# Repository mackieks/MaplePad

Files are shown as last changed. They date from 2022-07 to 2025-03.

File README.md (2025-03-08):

# MaplePad🍁<br/>

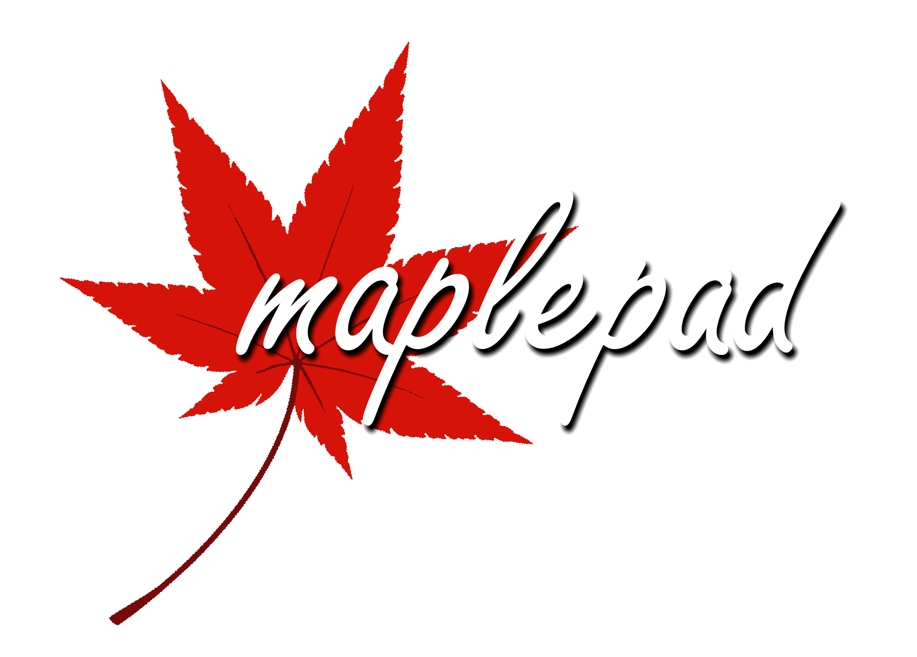
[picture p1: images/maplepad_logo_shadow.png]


MaplePad is an all-in-one Dreamcast controller, VMU, and Purupuru (rumble pack) emulator for Dreamcast portables and custom Dreamcast controllers. It runs on RP2040 and is usable with the Raspberry Pi Pico as well as custom MaplePad PCBs. See the [hardware folder](https://github.com/mackieks/MaplePad/tree/main/hardware) for a wiring diagram.

**Note:** MaplePad is still a WIP. You may experience issues with [Windows CE games](https://segaretro.org/Windows_CE). In almost all problematic titles, disabling VMU and rumble through the MaplePad menu will make the game playable. Check out the [Compatibility List](https://docs.google.com/spreadsheets/d/1JzTGN29Ci8SeuSGkQHLN1p6ayQNWUcsNw77SMujkjbs/edit?usp=sharing) for details!

## Features
With MaplePad you can cycle through 8 200-block internal VMUs with custom icons and colors, use an I2C or SPI OLED display to see the VMU screen in color and at 2x integer scale, and enjoy rumble that is 1:1 with the Performance TremorPak in most retail software (still some minor bugs!)

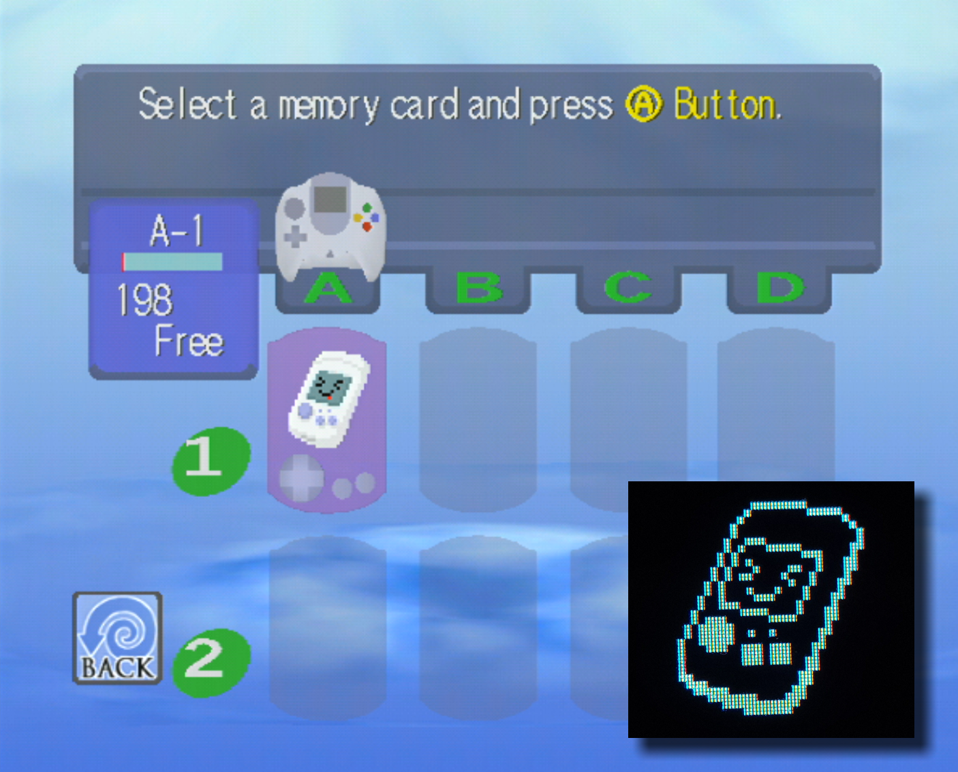
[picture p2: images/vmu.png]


### Feature List:
- [x] Full FT<sub>0</sub> (controller) support including analog joystick and triggers
- [x] Full FT<sub>1</sub> (storage) support for savegames with 1600 blocks of space
- [x] Multipaging for memory card (8 separate 200-block memory cards)
- [x] Full FT<sub>2</sub> (LCD) support with SSD1331 96\*64 color SPI OLED for VMU display (monochrome SSD1306 128\*64 I2C OLED also supported)
- [x] Customizable color palettes for all 8 internal memory cards
- [x] Robust FT<sub>8</sub> (vibration) functionality (WIP)
- [x] Robust FT<sub>3</sub> (timer/RTC) reporting for compatibility purposes (no RTC)
- [x] Basic menu on SSD1306 and SSD1331 OLED for configuring MaplePad behavior (WIP)

### To-do: 
Release v1.6 is gated by the following TODOs
- [ ] Finish menu (button test, VMU palette editor, misc. bugs)
- [ ] Address issues with non-CE games (Crazy Taxi, Blue Stinger, Powerstone 2)
- [ ] Finish FT<sub>8</sub> (vibration) continuous vibration and AST

Future TODOs
- [ ] Fix compatibility with Windows CE games
- [ ] Implement 'fancy' VMU color palettes (gradients, animated backgrounds, etc.)
- [ ] Implement option for DC boot animation on OLED
- [ ] Add external RTC for true FT<sub>3</sub> (timer/RTC) support
- [ ] Implement FT<sub>4</sub> (microphone) support

## Project Showcase
*StrikerDC MaplePad mod by Wesk*

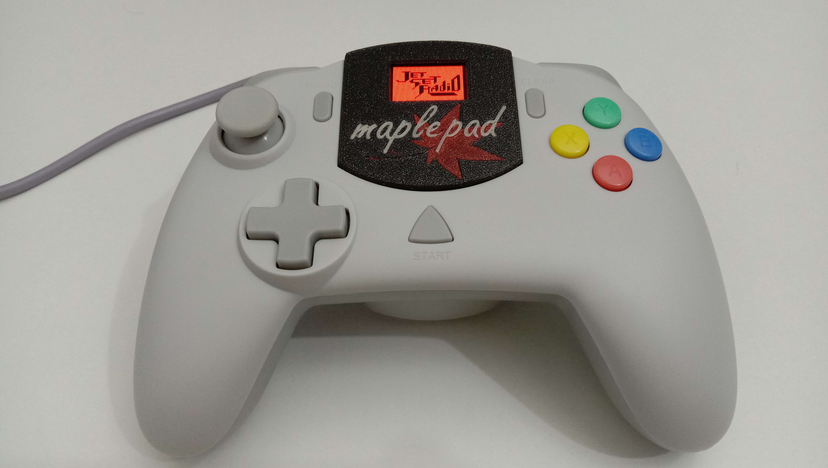
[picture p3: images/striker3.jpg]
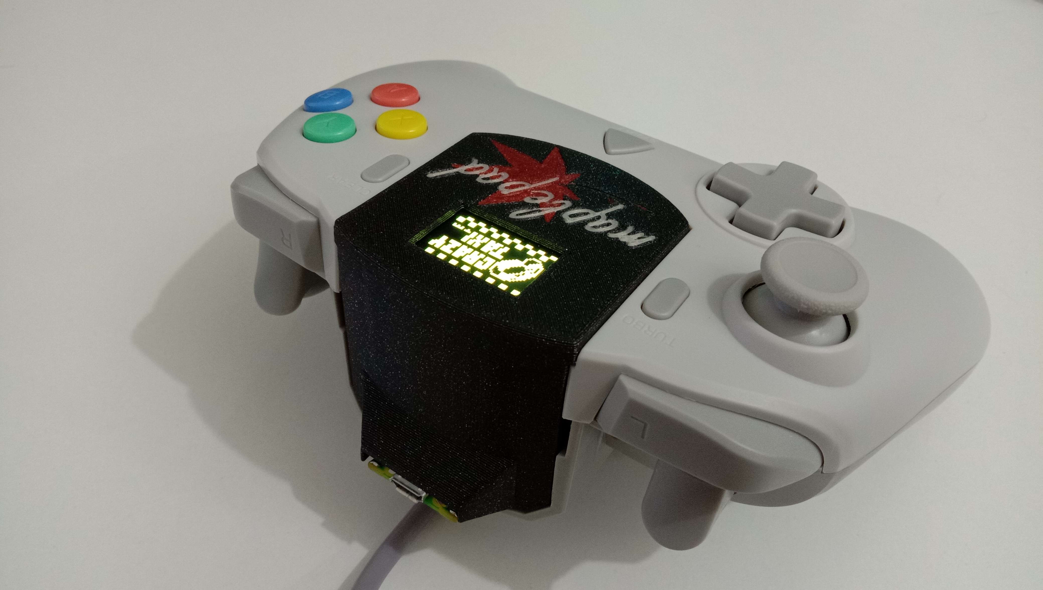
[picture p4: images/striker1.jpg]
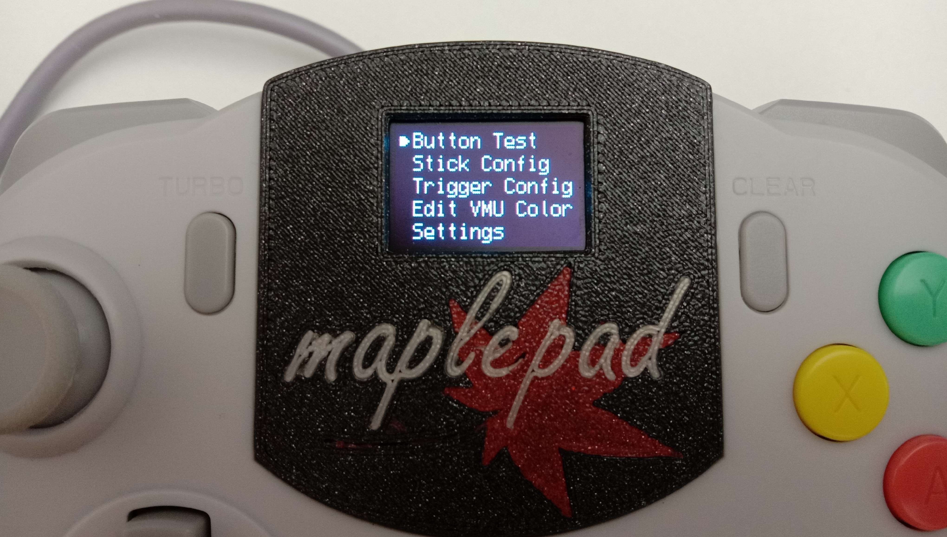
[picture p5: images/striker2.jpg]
  

*MaplePad Arcade Controller with VMU de GamesCare. [link](https://gamescare.com.br/produto/controle-arcade-dreamcast-tela-de-vmu-e-8-vmus-virtuais-na-placa-maple-board/), [video](https://www.youtube.com/watch?v=b0IbSASR3B4/)*

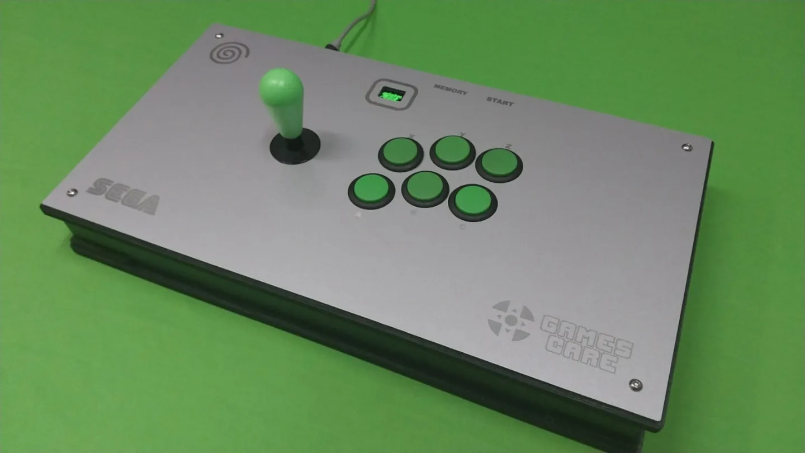
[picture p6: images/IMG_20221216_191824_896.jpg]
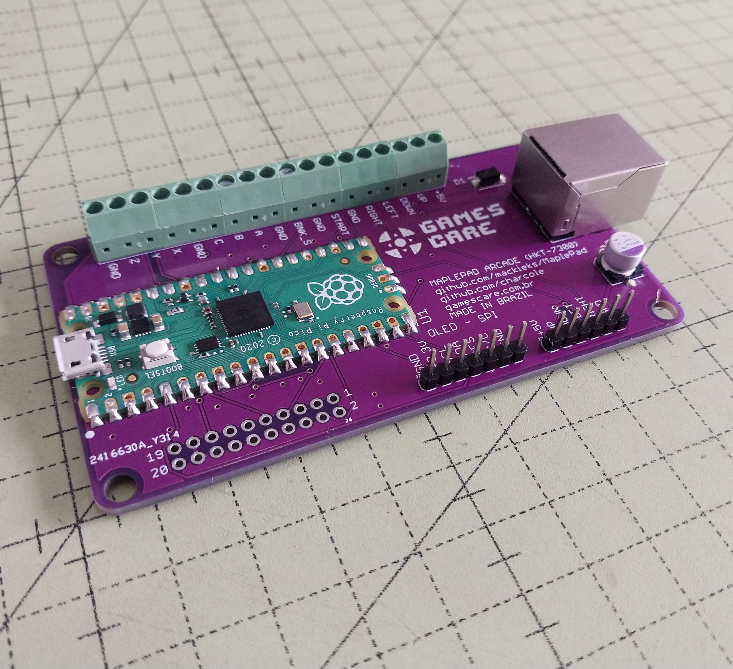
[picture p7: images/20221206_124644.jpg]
 

*Mini Arcade Stick de Mundo Yakara Colombia. Excellent video that showcases MaplePad v1.5 features! [video](https://www.youtube.com/watch?v=jbHO3rEyzZU)*

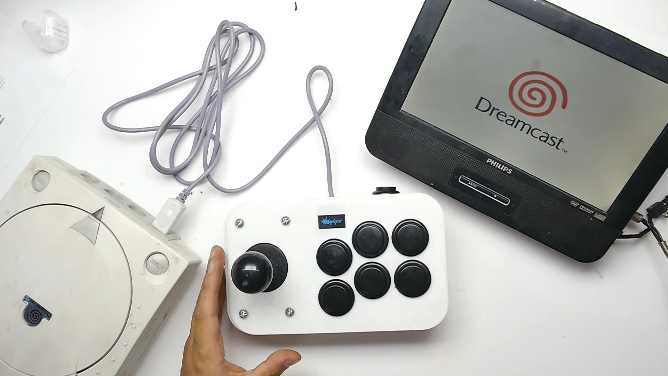
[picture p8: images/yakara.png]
 

*Mini plug'n'play virtual memory card by jounge. [link](https://tieba.baidu.com/p/8465994390)*

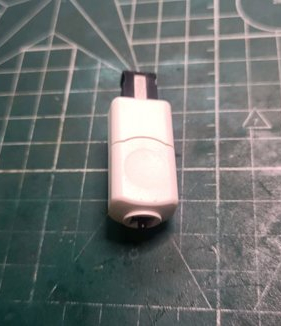
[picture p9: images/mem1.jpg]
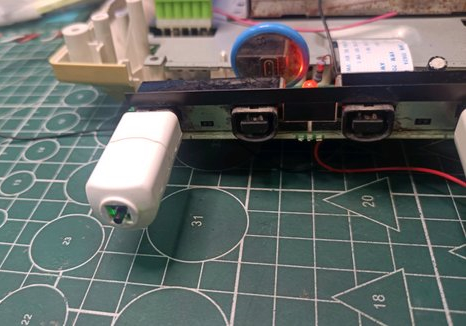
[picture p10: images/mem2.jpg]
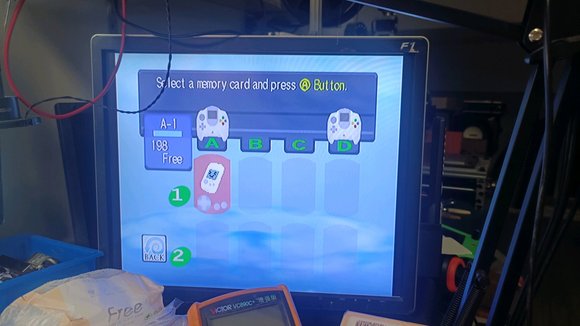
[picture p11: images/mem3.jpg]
  

*Various JAMMA Dreamcast adapters available on AliExpress. [link 1](https://www.aliexpress.us/item/3256805216279752.html), [link 2](https://www.aliexpress.us/item/3256804674679708.html), [video](https://www.youtube.com/shorts/UciW3vM-KWo) (flashing lights warning!)*

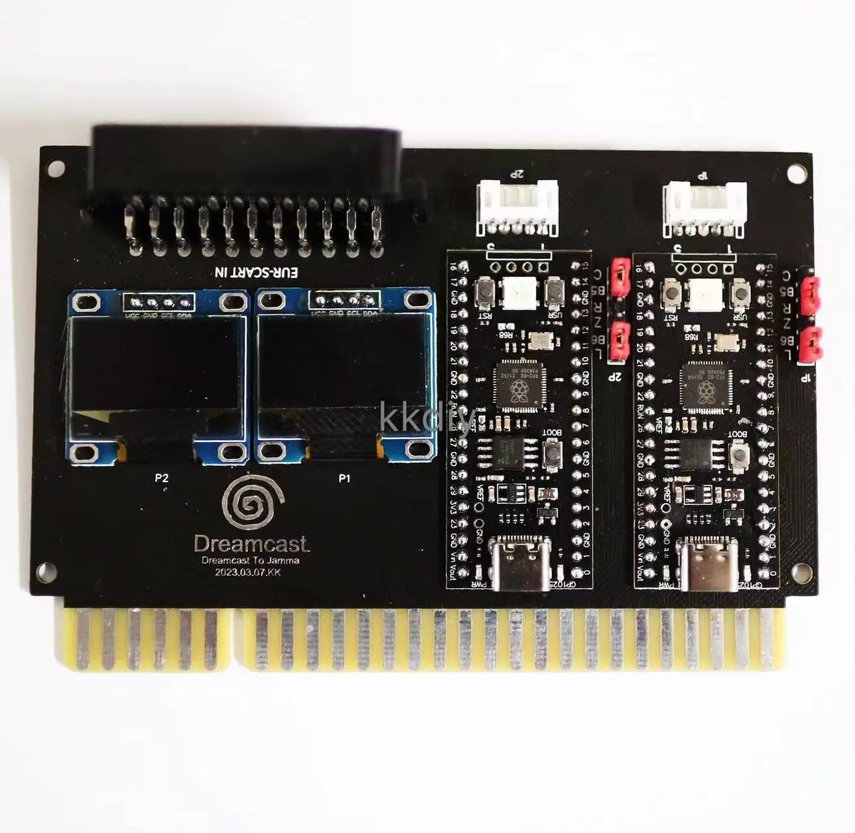
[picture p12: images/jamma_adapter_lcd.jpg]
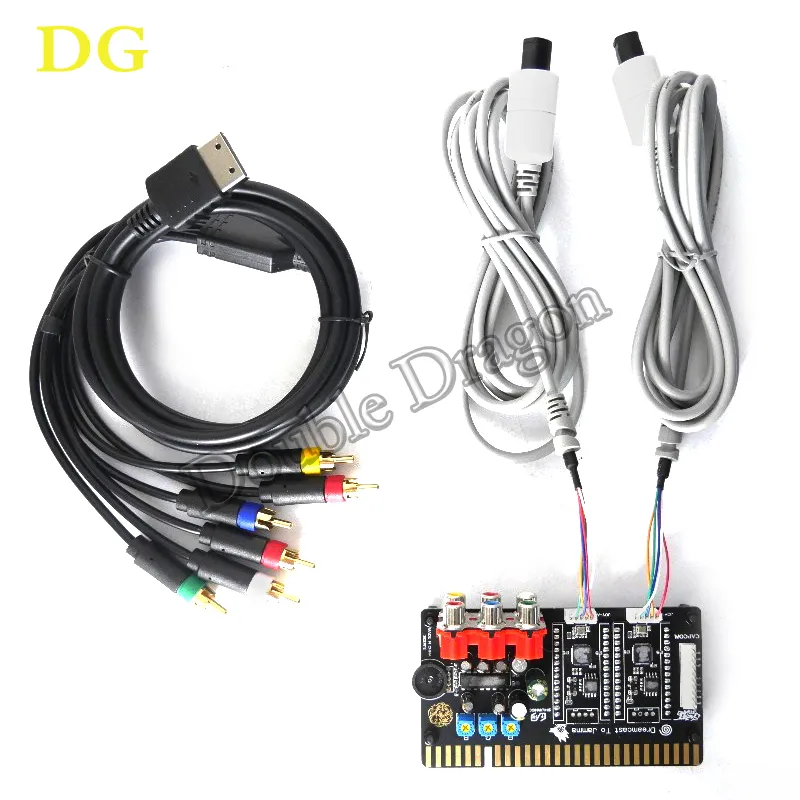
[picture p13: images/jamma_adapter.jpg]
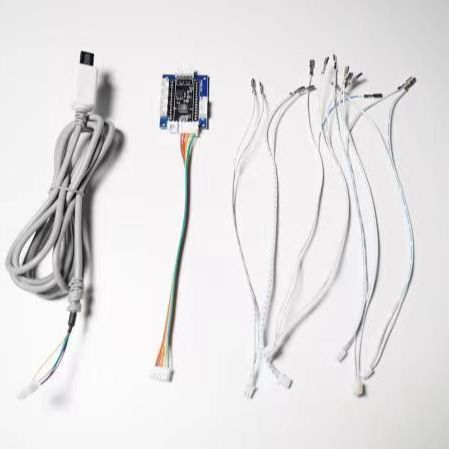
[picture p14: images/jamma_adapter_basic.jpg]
   

*Giant Dreamcast VMU + Arcade Stick by CrazyJojo (code modified). [video](https://www.youtube.com/watch?v=bEA_On7P_g8)*

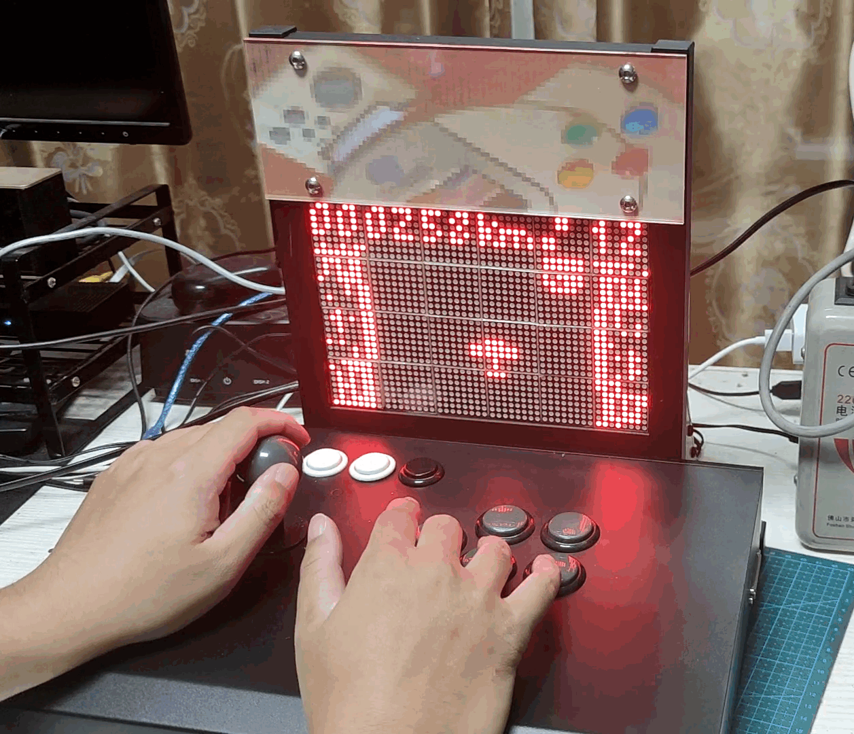
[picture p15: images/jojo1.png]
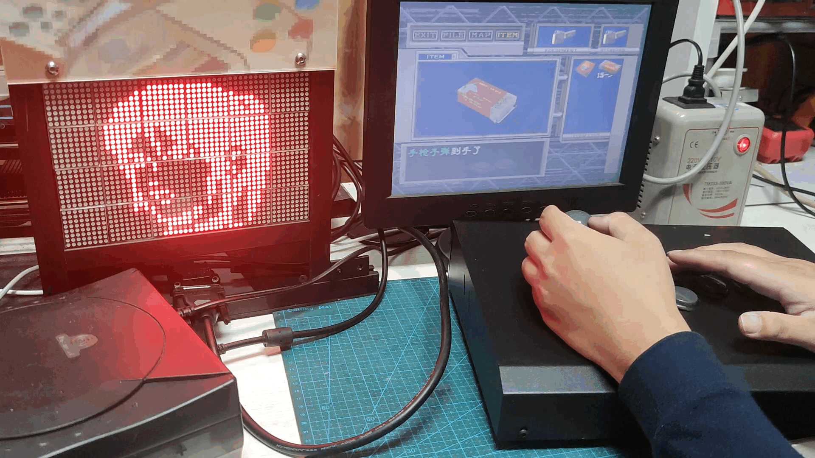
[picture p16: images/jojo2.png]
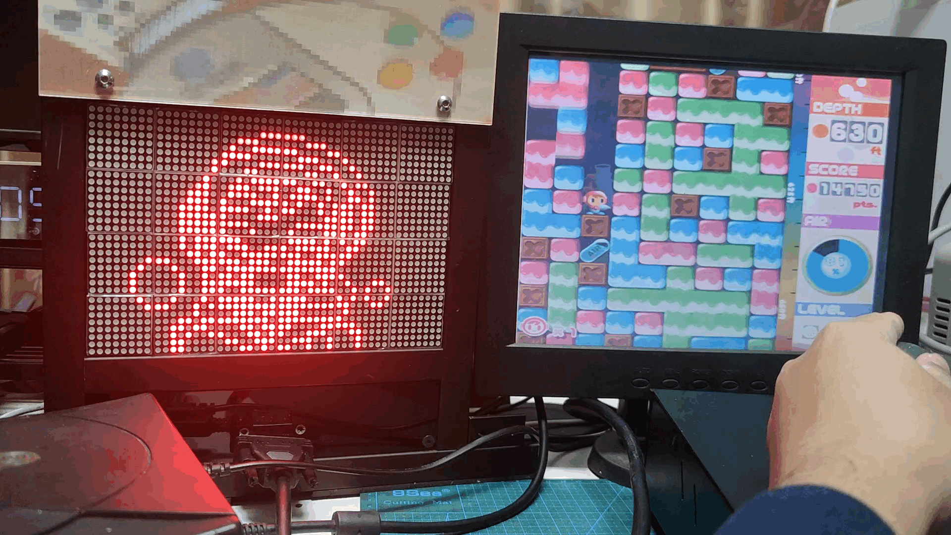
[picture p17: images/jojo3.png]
   

## Dumping VMUs to PC
You can use [picotool](https://github.com/raspberrypi/picotool) to dump VMUs manually. Here's the process:

- Put RP2040 into programming mode with BOOTSEL button and connect it to your PC
- Use picotool to dump whichever VMU page you want: `picotool save -r 10020000 10040000 dump1.bin`

- VMUs start at 0x10020000 and each one is 0x20000 long. So to save page 7, for example, you'd use 
`picotool save -r 100E0000 10100000 dump7.bin`
- Open dump in [VMU Explorer](https://segaretro.org/VMU_Explorer)


## License
<br />This work is licensed under a <a rel="license" href="http://creativecommons.org/licenses/by/4.0/">Creative Commons Attribution 4.0 International License</a>.

Share — copy and redistribute the material in any medium or format <br />
Adapt — remix, transform, and build upon the material for any purpose, even commercially. <br />
Attribution — You must give appropriate credit, provide a link to the license, and indicate if changes were made. <br />

MaplePad is forked from [Charlie Cole's Pop'n Music Controller.](https://github.com/charcole/Dreamcast-PopnMusic)

Special thanks: [Charlie Cole](https://github.com/charcole), [Colton Pawielski](https://github.com/cepawiel) and [Wesk](https://www.youtube.com/channel/UCYAwbbBxi5_LK8WVrD10SUw).

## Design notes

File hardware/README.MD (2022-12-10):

# Raspberry Pi Pico

Wiring diagram for Raspberry Pi Pico: 

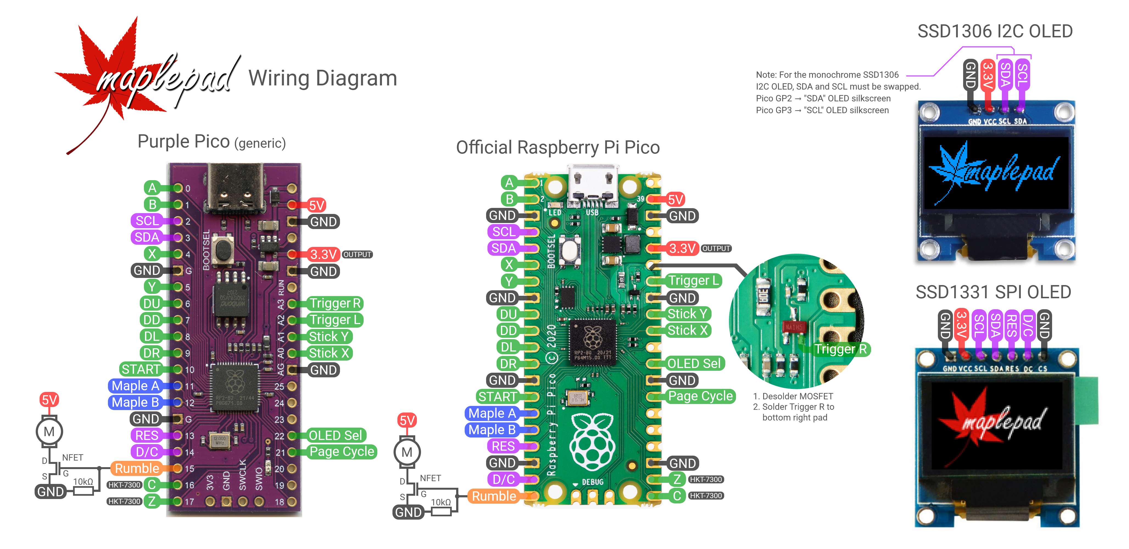
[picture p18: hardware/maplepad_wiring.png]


Notes:
- Do not connect a USB cable to the Pico when it is connected to the Dreamcast. (5V will backfeed to console!)
- The official Raspberry Pi Pico must be modded to access the right trigger pin (ADC3). See the wiring diagram for details.
- For rumble, use an N-channel FET with V<sub>GS(th)</sub> < 3V and I<sub>d</sub> ≥ 1A. Both large Xbox-style ERMs and coin-type vibration motors work well.
- You can add a freewheel diode between 5V and the NFET's drain if you'd like, but it's not necessary for prototyping.
- Connect OLED_SEL to GND to select the SSD1306 OLED. Leave floating to select the SSD1331 OLED.
- When wiring the SSD1306 I2C OLED, SDA and SCL need to be swapped and will not match the silkscreen on the OLED PCB. See the wiring diagram for details.
- The SSD1331 SPI OLED runs at a high clock speed. Use at least 34AWG wire and keep the wires short and direct.

# MaplePad 

Replacement Dreamcast controller PCB for portablizing, using RP2040. EAGLE source, Gerbers, BOM and assembly drawing are available in this directory. (Photo below is of the previous revision which lacked the BOOTSEL button.)



Recommended board fabrication specs: 
- 0.8mm 2-layer PCB
- ENIG (for chipscale BGAs)
- Red soldermask - optional, but in keeping with the Japanese maple theme :) 

JLCPCB may grow the drills under the flash to meet their spec-- this is OK. Also please note that the extremely small castellations often result in many 'crushed barrels' that require manual cleanup.

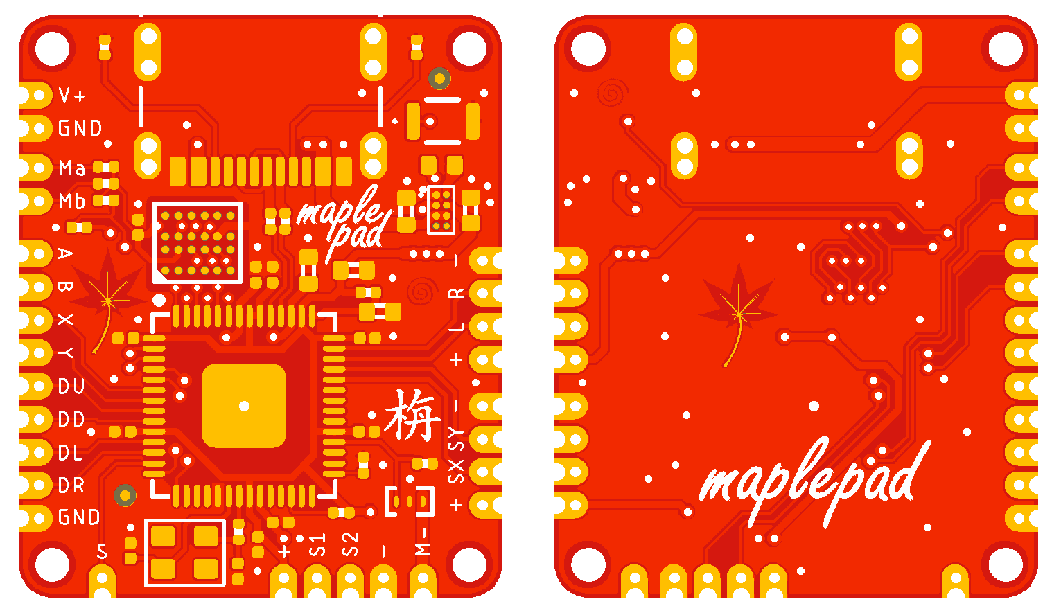
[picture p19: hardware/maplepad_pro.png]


Features:
- [x] 18.5 x 22.4mm 2-layer PCB
- [x] USB-C and BOOTSEL button for programming
- [x] Full Dreamcast controller compatibility
- [x] Analog joystick and triggers
- [x] VMU emulation (8-page VMU, 1600 blocks total)
- [x] SPI/I2C OLED for VMU screen
- [x] Rumble (Purupuru) support (WIP)
- [x] Power from 1.8V - 5.5V

What it doesn't support:
- [ ] Dual analog sticks
- [ ] Dreamcast Microphone
- [ ] Dreamcast Keyboard, Mouse, or Fishing Controller

A future version may support these features.

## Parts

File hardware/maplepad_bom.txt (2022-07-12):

Part   Value              Device                  Package                                                      
C1     10uF               C-USC0402               C0402                  
C2     15pF               C-USC0201               C0201                  
C3     15pF               C-USC0201               C0201                  
C4     10uF               C-USC0402               C0402                  
C5     0.1uF              C-USC0201               C0201                  
C6     0.1uF              C-USC0201               C0201                  
C7     0.1uF              C-USC0201               C0201                  
C8     0.1uF              C-USC0201               C0201                  
C9     0.1uF              C-USC0201               C0201                  
C10    0.1uF              C-USC0201               C0201                  
C11    0.1uF              C-USC0201               C0201                  
C12    1uF                C-USC0402               C0402                  
C13    0.1uF              C-USC0201               C0201                  
C14    0.1uF              C-USC0201               C0201                  
C15    1uF                C-USC0402               C0402                  
C16    2.2uF              C-USC0402               C0402                                   
IC1    RP2040_QFN56       RP2040_QFN56            QFN56_7MM_REDUCEDEPAD  
J2     2171790001         2171790001              2171790001_MOL                          
L1     MCEE1005T1R0MHN    L0402                   R0402                                 
R1     10k                R-US_R0201              R0201                  
R2     5.1k               R-US_R0201              R0201                  
R3     1k                 R-US_R0201              R0201                  
R4     10k                R-US_R0201              R0201                  
R6     200                R-US_R0201              R0201                  
R7     22                 R-US_R0201              R0201                  
R8     22                 R-US_R0201              R0201                  
R9     4.7k               R-US_R0201              R0201                  
R10    4.7k               R-US_R0201              R0201                  
R11    5.1k               R-US_R0201              R0201                  
R12    0-ohm for I2C OLED R-US_R0201              R0201                  
R13    10k                R-US_R0201              R0201                  
R14    1k                 R-US_R0201              R0201                                 
S1     GSNAN0T000101      GSNAN0T000101           GSNAN0T000101                           
U$1    ISL9122A           ISL9122A                ISL9122A               
U$25   W25Q128JVYIQ-TR    W25Q128JVYIQ-TR         WLCSP24                
U1     CSD17585F5T        CSD17585F5T             YJK3_TEX                                
Y1     12MHZ              FA-20H 12.0000MD30Z-K3  CRYSTAL_2.5X2

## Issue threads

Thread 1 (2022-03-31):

Arcade Stick version?

gamecenterjun, 2022-03-31:
Is it possible to make an arcade stick version for this? Basically the same thing, but using C and Z buttons instead of L and R triggers, since digital inputs are better than analog for arcade sticks and games. It would be fantastic if this were possible!

mackieks, 2022-04-05:
Hi! Sure, that's easy. If you don't need VMU LCD functionality, it might be easier for you to start from Charcole's original Pop'n Music controller code, since you wouldn't have to strip out MaplePad's analog stick/trigger code. Either way the edits would be similar.

First you'd need to make some changes to the main controller InfoPacket:

```
void BuildInfoPacket()
{
	InfoPacket.BitPairsMinus1 = (sizeof(InfoPacket) - 7) * 4 - 1;

	InfoPacket.Header.Command = CMD_RESPOND_DEVICE_INFO;
	InfoPacket.Header.Recipient = ADDRESS_DREAMCAST;
	InfoPacket.Header.Sender = ADDRESS_CONTROLLER_AND_SUBS;
	InfoPacket.Header.NumWords = sizeof(InfoPacket.Info) / sizeof(uint);

	InfoPacket.Info.Func = __builtin_bswap32(FUNC_CONTROLLER);
	InfoPacket.Info.FuncData[0] = __builtin_bswap32(0x000f06fe); // What buttons it supports
	InfoPacket.Info.FuncData[1] = 0;
	InfoPacket.Info.FuncData[2] = 0;
	InfoPacket.Info.AreaCode = -1;
	InfoPacket.Info.ConnectorDirection = 0;
	strncpy(InfoPacket.Info.ProductName,
			"Dreamcast Controller          ",
			sizeof(InfoPacket.Info.ProductName));

	strncpy(InfoPacket.Info.ProductLicense,
			// NOT REALLY! Don't sue me Sega!
			"Produced By or Under License From SEGA ENTERPRISES,LTD.     ",
			sizeof(InfoPacket.Info.ProductLicense));
	InfoPacket.Info.StandbyPower = 430;
	InfoPacket.Info.MaxPower = 500;

	InfoPacket.CRC = CalcCRC((uint *)&InfoPacket.Header, sizeof(InfoPacket) / sizeof(uint) - 2);
}
```

This is the Maple packet the controller sends to the Dreamcast to identify itself. InfoPacket.Info.FuncData[0] should be updated to indicate the buttons the Arcade Stick supports (Dpad, ABXYCZ, Start) based on Sega's official Arcade Stick documentation (05_Svs090e.doc in [Kochise's dreamcast-docs](https://github.com/Kochise/dreamcast-docs/tree/master/CONTROLR/DOCS)). It's also wise to match Sega's spec for the ProductName and Power fields, just to be safe.

Then you'd just need to update the buttons themselves-- increase the NUM_BUTTONS macro to 11, and add the new buttons (including the GPIOs you wire them to, and their bitmask as per Sega's controller docs) to the ButtonInfo struct. You can see the unused C button left over from Charcole's Pop'n Music controller below.

```
static ButtonInfo ButtonInfos[NUM_BUTTONS]=
{
	{ 0, 0x0004},	// Red centre, A
	{ 1, 0x0002},	// Green right, B
	{ 4, 0x0400},	// Blue right, X
	{ 5, 0x0200},	// Yellow right, Y
	{ 6, 0x0010},	// Yellow left, UP
	{ 7, 0x0020},	// Green left, DOWN
	{ 8, 0x0040},	// White left, LEFT
	{ 9, 0x0080},	// Blue left, RIGHT
	{ 10, 0x0008}	// White right, START
	// { 13, 0x0001}	// White right, C
};
```

Finally, if using MaplePad's codebase, you would need to remove or comment out all the analog stick and trigger code in SendControllerStatus(), so it doesn't mess up the packet checksum. If you use Charcole's original codebase you don't have to worry about this.

Hopefully that answers your question. If you'd like me to make a branch of MaplePad with these changes, let me know and I'll see what I can do!

gamecenterjun, 2022-04-09:
I have no coding experience, so I think I'd mess it up pretty easily if I tried to do it myself! It would be perfect if you could make a branch for the Arcade stick version!

ez2torta, 2022-04-24:
i forked this and did a version with L and R as buttons instead of triggers.

https://github.com/ez2torta/MaplePad/

gamecenterjun, 2022-04-26:
Exactly what I needed! Thank you!! I'll be trying this out soon!

mackieks, 2022-09-09:
I've been including an HKT-7300 binary in each release, so I'm going to close this. Saw on Twitter you made an arcade stick with it!  Very cool!

Closed 2022-09-09.

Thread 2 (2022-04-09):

BOM location

DAZHUANG2022, 2022-04-09:
This is great. I downloaded it. But the BOM list doesn't mark the locations. Hope you can mark them. Thanks

mackieks, 2022-04-12:
Hi there! Glad you like it.

The hardware documentation is minimal because I have a new revision with some major improvements coming soon. In fact, the PCBs just arrived yesterday! Once I've assembled and tested the new board, I'll update the hardware folder with a complete BOM, gerbers, and assembly info, as well as updated firmware to support it. I wouldn't recommend building the old board-- the 0201 footprints are a little too small and don't work very well.

DAZHUANG2022, 2022-04-12:
Hi this is really very good news. I also saw that 0201 is hard to solder by hand. Very looking forward to the new version. Thanks

mackieks, 2022-07-12:
I've uploaded the new hardware revision as well as a complete BOM and assembly diagram to the 'hardware' folder. However, the software doesn't completely support the new board, so I can't recommend it for general use yet.

DAZHUANG2022, 2022-07-12:
> I've uploaded the new hardware revision as well as a complete BOM and assembly diagram to the 'hardware' folder. However, the software doesn't completely support the new board, so I can't recommend it for general use yet.

Thank you I will continue to follow him Thank you for your efforts Looking forward to his new version

Closed 2022-07-12.

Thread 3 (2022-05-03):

Only works on first controller port

gamecenterjun, 2022-05-03:
Finally got this working, but I wired one and I found that it only works on the first controller port.

I tried it on Marvel Vs Capcom 2, which grays out the Vs mode option if there are less than two controllers. The VS Mode option just blinks really fast if I connect a regular controller on the first port and a Maplepad to the second port. If I put MaplePad on the first and the stock controller on the second port, it works fine. Any ideas about what's going on?

mackieks, 2022-05-03:
MaplePad is mostly for portablizing where only controller 1 is used, but the code handles different port addresses so it should work. I will try to reproduce the failure on my setup. Maybe MVC2 is doing something weird or there's a bug in my subperipheral packets.

Have you made any modifications to the code?

mackieks, 2022-05-04:
OK, I solved the issue by reworking how the port number is handled in the "Absolute Position" field of the data packets. I tested in MVC2 and the VS menu is working as expected with OEM controller in Port A and MaplePad in Port B.

Here's the ad-hoc build I'm testing with. Please let me know if you're able to verify the fix on your hardware. Be warned: I'm right in the middle of implementing a bunch of new features, so use it at your own risk.
[maple_pio.zip](https://github.com/mackieks/MaplePad/files/8617386/maple_pio.zip)

gamecenterjun, 2022-05-04:
Thank you! Will test this today and report back.

gamecenterjun, 2022-05-04:
Alright, that worked! I have two MaplePads on and versus mode stays on. It looks like the new version is sending random directional inputs at random times, but I have the board wired to an arcade stick so it could be that some directions are wired to ground. I'll test it more later!

mackieks, 2022-05-04:
Cool, glad to hear it worked. Just FYI, the software is still very much in development and isn't ready for general use yet. The build I sent is set up to use an analog stick and analog triggers with calibration data stored in the flash memory, among other things.

Eventually I can work on a version that emulates a real arcade stick (HKT-7300) using a stock Pico, but right now I'm focused on more portablizing-focused things like a settings menu on the VMU, guided calibration for sticks and triggers, etc.

gamecenterjun, 2022-05-04:
Yeah, it's not really usable at since the stick has random inputs but you figured out how to make it work for 2p! Excellent work! Can't wait for the release!

I'm building a Dreamcast to arcade cabinet adapter and using these pi pico MaplePad boards for controls. I'm happy to run it in single player for now. Thank you!

Closed 2022-05-04.

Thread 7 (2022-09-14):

Compatibility with "regular" Raspberry Pico

eduardokenj, 2022-09-14:
The maplepad works with raspberry pico with default 2MB SPI memory? Because i wish build an a "easy" DIY board for my arcade stick.

mackieks, 2022-09-15:
Hi! Yes, it works on the regular Pico. Look at `maple.h` to see which GPIO pins to connect buttons to.

(Once I fix some more compatibility issues, I'll upload wiring diagrams for making custom controllers/arcade sticks.)

Closed 2022-09-16.

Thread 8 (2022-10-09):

Random disconnection

eduardokenj, 2022-10-09:
I'm use the release v1.4c-arcade on my raspberry pico. In memory menu on bios look like i connect and quickly disconnect the controller, and in 240p test suite in "Maple Devices" item, when i select the maplepad or another controller, the maplepad "disconnect" when I back to menu.

PS: Thanks to your dedication for this project

mackieks, 2022-10-12:
Thanks for reporting the problem! I'll debug this next week.

Wesk87, 2022-10-14:
Tested on my side and found no faults with the build. @eduardokenj you may have noise in the data line. Try shortening the line or shielding it.

mackieks, 2022-10-16:
Also confirmed working on my end. This sounds like a hardware problem, not an issue with the build. Make sure you've followed the wiring diagram in the hardware folder, and check your Pico for cold solder joints or shorts. A loose controller plug or faulty Dreamcast controller daughterboard could also be at fault.

mackieks, 2022-10-16:
OK, I did find a minor discrepancy between official HKT-7300 and MaplePad (MaplePad's arcade stick Free Device Status and power consumption weren't right) but nothing in the BIOS, 240P Test Suite, or retail SW cares about those fields. You're welcome to try this updated build though!
[maple_pio.zip](https://github.com/mackieks/MaplePad/files/9795966/maple_pio.zip)

eduardokenj, 2022-10-18:
Well, the new fw works fine, solved the issue... TKS

Closed 2022-10-18.

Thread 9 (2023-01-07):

I2C OLED can't working and bug on 1.4b pio version

hpx1984, 2023-01-07:
hi Sir

bug1
test 1.4b pio and found the i2c OLED display can't working , once connect I2C OLED display Dreamcast was disconnect PIO board
the screen on OLED as below
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

bug2
for the VMU, when format or copy some game save file on the VMU's last page (8th page) some times Dreamcast will disconnect the PIO board and need re-plug pio board for fix it

suggestion
now the FW is 1.4d but can't working on PIO board as my tested , is it possible for keep update PIO version FW?
and is it possible for read VMU file via USB port?

mackieks, 2023-01-07:
Hi!

- Bug 1 is a do not fix since it's happening on old firmware. Firmware 1.4d works with the SSD1306 I2C OLED in my testing
- Bug 2 is a known issue, but rarely happens in my tests. The best advice I can give you is to avoid copying large numbers of files at the same time, and wait a little while (~30s) after formatting/copying files before cycling pages or doing another copy.

You mentioned that 1.4d doesn't work on your hardware. Can you give me some more details? What RP2040 board are you using, and how much flash memory does it have? Are you connecting GPIO22 to GND to select the I2C OLED?

Regarding reading out VMU data over USB: it's currently not possible to do this while the controller is operating because the USB code slows down the Maple Bus code too much. However, you can use [picotool](https://github.com/raspberrypi/picotool) to dump VMUs manually. Here's the process:

- Put RP2040 into programming mode with BOOTSEL button
- Use picotool to dump whichever VMU page you want: `picotool save -r 10020000 10040000 dump1.bin`
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
- VMUs start at 0x10020000 and each one is 0x20000 long. So to save page 7, for example, you'd use
`picotool save -r 100E0000 10100000 dump7.bin`
- Open dump in [VMU Explorer](https://segaretro.org/VMU_Explorer)
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

hpx1984, 2023-01-08:
many thanks your quickly replied
this is really a great project

my board can working with 1.4b , but 1.4c and 1.4d once plug the board to DC the DC will show controller and vmu icon and then after 0.5s the board may disconnect with DC (no icon show on TV's DC VMU screen)

i use green board(maybe 4M，i'm not sure） and black board(memory PY25Q128 16M)
the green board seems same as the picture "wiring.png"'s official board
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

so also can use picotool for program vmu data into the maple VMU, right?
like this :picotool load dump1.bin 10020000 10040000

i'm think about if possible for load more pages of VMU like 16 pages?

mackieks, 2023-01-08:
I just reflashed firmware 1.4d on my test controller and both the standard and arcade versions are working fine. You might have a hardware issue, like power or ground wires that are too thin or too long. Can you share photos of your wiring?

Yes, you should be able to load VMU data into the flash using picotool. However having more than 8 VMU pages would require changes to the code. I think the current 1600 blocks of space is enough for most use cases, and going to 12 or 16 would severely limit space for storing other data, like sprites/animations for the MaplePad menu.

hpx1984, 2023-01-08:
Dear Sir

but i'm just change the FW to 1.4b the system all working fine(include 1331 OLED and vmu) ,once change FW to 1.4d then got this problem

now i test on purple board the I2C OLED can show maplepad logo and hold on this logo, and the DC still loss connect after 0.5s

the wires seems not very long, i will test again for short the wires
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

plug the board on DC A controller port, just saw the controller and vmu icon 0.5s and then loss the icon
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

mackieks, 2023-01-08:
What revision Dreamcast are you using? Is it a VA0 by chance?

hpx1984, 2023-01-08:
Dear Sir Mackieks

test again for short the DC controller cable ,can't fix the problem
1.4d can't working,
1.4b good working
Dreamcast HKT-3010 NTSC J, but i don't know the main board number , the Dreamcast product label hasn't print this information, i can disassemble it later

mackieks, 2023-01-08:
Ok, no problem. I'll look into this more over the next few days and will keep you posted.

mackieks, 2023-01-08:
@hpx1984 Found a bug in the code and fixed it. Can you test this uf2 and see if it fixes your problem?
[maplepad.zip](https://github.com/mackieks/MaplePad/files/10369454/maplepad.zip)

hpx1984, 2023-01-08:
Dear Sir Mackieks

this version can working now , good fixed sir
Dreamcast can detected the controller and VMU and i2c OLED also working good

but still has bug: once change page by used GPIO21 to GND then the controller and vmu loss on Dreamcast VMU page

mackieks, 2023-01-09:
I can't replicate the controller disconnect when cycling pages. Does it also happen when you cycle pages with Start + D-pad Left or Start + D-pad Right?

hpx1984, 2023-01-09:
i just test the VMU and OLED without controller function , i think i can use some wires for test cycle pages with start+ D-pad

mackieks, 2023-01-12:
@hpx1984 Any updates?

If you're still experiencing disconnects when cycling, maybe do a nuke_flash using the .uf2 I linked a few messages up, then reflash MaplePad.

hpx1984, 2023-01-14:
Dear Sir Mackieks

used unke_flash then used 1.4d still can't use GPIO21+GND for cycle VMU,
if use start+D PAD can cycle VMU

mackieks, 2023-01-16:
Ok, that's a separate issue I'll have to debug later. Since you're able to cycle VMUs with the button combo, I'm going to close this for now.

hpx1984, 2023-01-17:
Dear Sir Mackieks

now very easy disconnect the VMU once format it and it can not fix by un-plug and re-plug into Dreamcast (use nuking uf2 for fix it)
i do format it just want to set different Icon for let to easy for know which VMU i use when in the game
now the icon is same on I2C OLED screen (same color and same icon)

so just suggest if can't fix this disconnect bug then please change different VMU Icon in next FW update

hpx1984, 2023-01-20:
i play game and use this VMU for game save ,the screen is show game name so seems different VMU Icon is not impotent

rpf16rj, 2023-02-17:
Hi, i have same problem, but with standard controller. In some momments the controller stop work and when i connect, the display turn on with logo maplepad but not work. In 240p suit test, the controller is power on and imediatly disconnect at less a second.

About the calibration of stick, i don't got the axis X and Y work with real sensitive. I have that calibrate more times to got the sensitive work better, but not perfect. The movement skip the 0 to 125.

Another problem, but i don't think that be a conde problem, but my display in games like crazy taxi where stay changing animation in all time, the picture broken and stay crazy.

mackieks, 2023-02-17:
I know I sound like a broken record, but display *and* controller issues really does seem like a hardware issue. Can you share photos of your setup and soldering? And have you tried with the firmware from [this comment](https://github.com/mackieks/MaplePad/issues/9#issuecomment-1374924291)?

The calibration/stick scaling isn't bulletproof, but it's pretty decent. However, it can't compensate for sticks that jitter or jump around (the Alps sticks on my Dualshock 4 do this). I need to rewrite the calibration stuff to fix this, just haven't yet.

rpf16rj, 2023-02-18:
> I know I sound like a broken record, but display _and_ controller issues really does seem like a hardware issue. Can you share photos of your setup and soldering? And have you tried with the firmware from [this comment](https://github.com/mackieks/MaplePad/issues/9#issuecomment-1374924291)?
>
> The calibration/stick scaling isn't bulletproof, but it's pretty decent. However, it can't compensate for sticks that jitter or jump around (the Alps sticks on my Dualshock 4 do this). I need to rewrite the calibration stuff to fix this, just haven't yet.

So, i tested the firmware from that you tell me, work fine but this is for arcade, my prototype is a standard joystick.
But, i used some firmwares from of releases from the 1.3 and this also, and now aparently work whout give old problem.
Note: The both analogic L and R i got calibrate perfectly.

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

rpf16rj, 2023-02-19:
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

Hi, i discovery the problem with display. I replace to another display and now working fine. Sorry for get your time.
This project is amazing, congratulations for this.

mackieks, 2023-02-19:
Glad you figured it out. I just pushed a new release that includes the patches from that build I linked earlier. Feel free to open a separate issue if you encounter more bugs.

Closed 2023-02-19.

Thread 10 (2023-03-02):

Weak rumble in numerous titles

mackieks, 2023-03-02:
**Description:**
Some games exhibit weak/faint rumble during gameplay. None seem to be WinCE games.
- Maybe a bug in the vibeHandler function? (unlikely)
- Or these games use continuous vibration, and the incomplete implementation is only generating one pulse and ending, instead of repeating the pulse until AST is hit (more likely)

**To-do:**
Capture logic traces with HKT-7300+Performance TremorPak and MaplePad to compare behavior.

**Affected titles:**
(tested on 1.4b)
- Fighting Vipers 2
- Looney Tunes Space Race
- Macross
- Marvel vs Capcom
- Mr. Driller
- Powerstone 2
- Sega Marine Fishing
- Soul Calibur

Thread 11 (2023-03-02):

Joystick range issues in numerous titles

mackieks, 2023-03-02:
**Description:**
Some games don't respond to diagonal joystick inputs properly.

**To-do:**
Capture logic traces with HKT-7700 and MaplePad to compare behavior. Maybe try a set joystick motion (like a clockwise circle) to capture the full range of values. Might need to use a debug load on MaplePad to print out stick values.

**Affected titles:**
(tested on 1.4c)
- Blue Stinger
- Star Wars Jedi Power Battles

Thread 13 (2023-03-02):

Rumble issues in Windows CE titles

mackieks, 2023-03-02:
**Description:**
One of many, many problems with WinCE software. Some titles don't detect rumble at all. Some titles advise that an unsupported accessory has been connected when rumble is enabled, and work fine with rumble disabled. Sega Rally 2 seems to detect rumble, but hard crashes when rumble actually activates in-game, i.e. when the DC sends a setCondition packet to MaplePad (how this is even possible is beyond me.)

This is probably a packet format issue, or a packet that isn't being handled correctly by MaplePad. I already fixed some bugs where MaplePad wasn't responding to GetMediaInfo packets properly, so maybe there are more issues like that lurking in the code. The worst possible scenario would be if the vibeHandler timer ISR is somehow interfering with the receipt/transmission of rumble-related packets. Also, maybe continuous vibration/AST not being implemented is causing problems...? Really need to address that.

**To-do:**
Capture logic traces with HKT-7700+stock VMU and MaplePad to compare behavior. Some analysis of Sega Rally 2 already performed last year.

**Affected titles:**
(tested on 1.4b/c)
- 4x4 Evolution (VMU icon shows up, but disappears. VMU isn't recognized as formatted)
- Bust-A-Move 4
- Ducati World Racing
- Hundred Swords
- Q*bert
- Resident Evil 2
- Sega Rally 2 (poster child for WinCE issues)
- Tom Clancy's Rainbow Six

mackieks, 2023-03-04:
Sega Rally 2 test from 9/17/22:

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

> Absolutely baffling... So in Sega Rally, going into the settings, selecting a rumble strength and pressing A will make the game send a SetCondition command to the rumble pack. But with Maplepad, the SetCondition command never gets sent when I press A.
> In fact the game instantly freezes
> how the controller could make the entire game loop freeze is beyond me

MaplePad's SendControllerStatus packet (A press) looks the same as the HKT-7700's in this capture. I did see some spurious spikes on the data lines after turning off the glitch filter in DSView. Maybe the next step is to capture this particular transaction with the scope and make sure this isn't a SI issue.

megavolt85, 2024-03-22:
the problem is that the current implementation of maple in pio is very crap and misses some packets, you need to completely rewrite the pio rx module and get rid of state_machine.c
advice from an experienced programmer, if you want to do it well, write your code, other people's code always contains errors

mackieks, 2024-03-22:
Thanks for the heads up! I'm no longer working on this project, but feel free to open a PR if you want to contribute

megavolt85, 2024-03-23:
I'm currently busy with my project of connecting USB keyboards/mouses to DreamCast.
initially I also used this library to process maple, but when I tried to connect a PS3 controller, I encountered the same problems as you, in the end I had to write PIO RX from scratch and change PIO TX so that it would work stably
P.S. I use only one core for maple, the second core is used for USB processing, and I do not use DMA for maple transfers

mackieks, 2024-03-23:
Sounds like your rewritten Maple Bus core works well. If it's abstracted enough to merge into MaplePad you're welcome to open a PR.

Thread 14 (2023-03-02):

Rumble not detected in some non-CE titles

mackieks, 2023-03-02:
**Description:**
A few non-CE games still don't detect rumble. Probably a trivial error in packet formats or the way MaplePad responds to certain DC packets; I already fixed a similar issue caused by MaplePad not responding to GetMediaInfo with the Purupuru-specific info packet.

**To-do:**
Capture logic traces with HKT-7700+stock VMU and MaplePad to compare behavior.

**Affected titles:**
(tested on 1.4c)
- Evil Dead: Hail to the King
- Red Dog
- Wacky Races

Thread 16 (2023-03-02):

Rumble issue in Crazy Taxi

mackieks, 2023-03-02:
**Description:**
In the settings menu of Crazy Taxi, enabling rumble will cause the rumble motor to run forever, or until the game sends a new rumble command (setCondition) during gameplay.

This is probably a continuous vibration/AST-related issue. See https://github.com/mackieks/MaplePad/issues/15

**To-do:**
Capture logic traces with HKT-7700+Performance TremorPak and MaplePad to compare behavior. Confirm that the game BlockWrites a new AST to the Performance TremorPak, and that it triggers a continuous vibration when rumble is enabled in the settings menu.

**Affected titles:**
- Crazy Taxi

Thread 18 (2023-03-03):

Conflict Zone – Unsupported Device

mackieks, 2023-03-03:
**Description:**
Conflict Zone's title screen says an unsupported device is connected and will not proceed further. Fixing this might help with other WinCE titles.

**To-do:**
Capture logic traces with HKT-7700 and MaplePad to compare behavior.

**Affected titles:**
- Conflict Zone

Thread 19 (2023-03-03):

KISS Psycho Circus – Unsupported Device

mackieks, 2023-03-03:
**Description:**
KISS Psycho Circus' title screen says an unsupported device is connected and will not proceed further. Fixing this might help with other WinCE titles.

**To-do:**
Capture logic traces with HKT-7700 and MaplePad to compare behavior.

**Affected titles:**
- KISS Psycho Circus

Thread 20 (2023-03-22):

MaplePad (VMU) on a Badger 2040

kadern0, 2023-03-22:
Hi @mackieks, this is not an issue but a question. Do you think it would be possible to run this project (at least the VMU emulator) on a [Badger 2040](https://shop.pimoroni.com/products/badger-2040)?

Regards!

mackieks, 2023-03-22:
Hi! The code will run on the Badger, but I only support SSD1306 and SSD1331 OLEDs for the VMU display right now. Porting the Badger's ePaper library wouldn't be hard, but even with partial refresh some games wouldn't look good due to the low display update rate. Case in point, Power Smash 2:

https://user-images.githubusercontent.com/49252894/227059879-80d3bab9-217f-49cf-a020-74a354a9a1b2.mp4

Games that display static images or simple animations, like Rez, might be OK with partial refresh.

https://user-images.githubusercontent.com/49252894/227061105-1d1b73f7-dd9d-40ce-8873-35c2165c08cc.mp4

Also, MaplePad isn't a standalone 'VMU emulator'. So you need to be connected to a Dreamcast or other Maple host to get VMU images (unless you gut the codebase and feed in dummy packets or something).

Keep in mind the Badger has a ton of onboard circuitry, so you'd have to remap pins in `maple.h` for the controller buttons, and cut traces and stuff for the ADC lines if you want joystick/trigger compatibility.

kadern0, 2023-03-23:
Thank you for your response. Totally agree that that the e-ink display might not show the best results on games that make a lot of use of the VMU's display. My idea was more about connecting the Badger to the Dreamcast 'just' to save/load games and use the on board buttons to switch between memory pages. Would that  be hard to achieve?

mackieks, 2023-03-23:
Got it. Wasn't sure what your use case was. Yes, that's doable.

You can connect the Badger to the P2/P3/P4 controller port and use its internal VMUs that way. The Dreamcast will register a controller being present on whichever port you choose, and you won't be able to connect an external controller to that port.

This is because retail software will only talk to subperipherals (VMU, rumble pack, microphone) if they are connected through a parent peripheral (controller or arcade stick). So you can't connect VMUs directly to the Dreamcast without a controller.

If you want to cycle pages with the Badger's buttons, update the `PAGE_BUTTON` macro in `maple.c` to the appropriate pin. The codebase is kinda broken right now, so base any edits off [commit b187916](https://github.com/mackieks/MaplePad/tree/b187916e5ac688214a89d33c4f908024896cdd28).

I'd also recommend compiling an arcade stick binary (set these defines in `maple.h`) because otherwise, the code will read in garbage from the Badger's ADC pins (pic below), and the joystick and triggers will do weird things.
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

At some point I want to develop a MaplePad-based "Super VMU" that you can plug into a stock controller for these sorts of use cases, but that's a long way off.

mackieks, 2023-04-05:
Closing this for now, lemme know if you have any other questions!

Closed 2023-04-05.

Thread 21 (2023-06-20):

Erroneous Right/Down constant pressing when used with separate controller.

Sharkeology, 2023-06-20:
I am current using the software of this project as a separate VMU to use with my console, it appears and functions perfectly however it will cause the directional pad Right or Down operations to constantly occur after being pressed on a controller connected to a different port. This can be fixed by pressing the button again, but makes any sort of gameplay incredibly difficult.

psxrester, 2024-01-13:
you should check your solder points, be careful if you use header pins, this could bend the Arduino and make a wrong connection, use flux for your solder points, don't forget to clean the flux after finishing, some flux can cause a mess if not cleaned properly

jamesfxh, 2024-09-04:
I have the same issue,D-pad up/Down triggered automatically.but only for standard firmware, Also flash Arcade firmware test it's ok.Why is that?

mackieks, 2024-09-04:
If you use the standard controller firmware, you need to wire up an analog stick and triggers, and run the calibration routines in the menu. You can't leave the analog inputs floating. If you do, you'll get random erroneous inputs like what you're describing.

Some workarounds:
- edit and recompile the firmware to hardcode the X and Y axes to 0x80
- wire up some resistor dividers to hold the stick inputs at VCC/2
- use the arcade stick firmware

jamesfxh, 2024-09-13:
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

Thanks bro
Refer to your workaround,Adjusted the stick & triggers inputs voltage,and run the calibration program in the menu.It's working fine now.
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

jamesfxh, 2024-09-13:
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

Thanks bro
Refer to your workaround,Adjusted the stick & triggers inputs voltage,and run the calibration program in the menu.It's working fine now.
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

Closed 2024-09-05.

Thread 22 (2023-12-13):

OLED display sh1106 support

psxrester, 2023-12-13:
Could be possible support OLED display sh1106 driver?

mackieks, 2023-12-14:
Hi! Yes, it's easy to add support for new OLEDs because the display.c functions are all abstracted, and the SH1106 is extremely similar to the SSD1306. I could add SH1106 support in a few days, but it's not a priority right now. I might get to it next year.

kaduleite, 2024-01-19:
I really loved to know about that. I got a display from Aliexpress ( [https://pt.aliexpress.com/item/1005006018476472.html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](https://pt.aliexpress.com/item/1005006018476472.html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) ) that says compatible to SSD1306 and I really like to use it because of its big size.
I've been hoping that it was plug and play compatible. My wiring are ok, I tested with other display and it works fine, but the new one only display trash.
So I really thank you if you add support for it.

kaduleite, 2024-03-04:
> Hi! Yes, it's easy to add support for new OLEDs because the display.c functions are all abstracted, and the SH1106 is extremely similar to the SSD1306. I could add SH1106 support in a few days, but it's not a priority right now. I might get to it next year.

Any news?

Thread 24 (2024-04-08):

Support SOCD cleaning (Simultaneous Opposing Cardinal Directions)

Paxtez, 2024-04-08:
It would be nice if MaplePad supported (if it doesn't already) SOCD cleaning, which is used on button style joysticks (Hitbox).  Often games don't know how to handle opposite directions since they were made with Joysticks / D-Pads in mind.

Ideally it would have options for different types of SOCD options:
- Off (don't filter)
- Neutral (L + R = None  &  U + D = None)
- Neutral/Up (L + R = None  & U + D = U)
- Last Win (L -> R  = R)
- First Win (L -> R = L)

mackieks, 2024-12-12:
The project is currently undergoing a complete rewrite to address the compatibility issues with certain games. Once it's complete, this feature will be added, with menu options to configure the SOCD behavior

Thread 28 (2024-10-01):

Bug with save VMU

Lhemamou, 2024-10-01:
Hi,

thanks for the project, it's awesome. I intend to use it in order to have access to a vmu to save games. The device is recognized but when i try to save something ( i test chuchu and crazy taxi ), the vmu disconnects, when i reset it directly via reset button on raspberry pi, the vmu is recognized again but the file can't load. Do you have any idea with this issue ?

For the setting, i am using only the pin of page cycle and input pins.

I will also probably do a PR to add the possibility to use the RP2040 zero if you don't mind :)

riggles1, 2024-10-12:
I'm also only interested in the virtual VMU portion of the project. Think it's possible to change it so that the rp2040 can be a hooked up as a memory slot device? (repurposing a cheap corruption prone third party memory card for the connector+shell)
I'm surprised that there aren't any projects that does this, but maybe the VMU<->Controller interfacing is complicated?

I don't know code, I'm just someone who prefers using the original wired controllers.

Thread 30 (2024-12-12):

[Feature request]Can we add support for HKT-7500 twin stick?

sky7068, 2024-12-12:
I looked up some [information,](https://dcemulation.org/phpBB/viewtopic.php?t=105365) but I don't know how to program.

mackieks, 2024-12-12:
Adding HKT-7500 support should be straightforward.

The project is currently undergoing a complete rewrite to address the compatibility issues with certain games. Once it's complete, HKT-7500 support will be prioritized for the next release

programmerta, 2025-01-11:
@mackieks The rewrite does support the option for a second analog stick. The only reason why it's not implemented right now is due to the lack of ADC channels on pico. Do the triggers of the HKT-7500 act as buttons or the R/L analog triggers? If they're buttons then that would free up the other ADC channels to be used for the second stick.

mackieks, 2025-01-11:
The HKT-7500 is fully digital:

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

The best approach is probably to reconfigure SX/SY/L/R to be the second set of directional inputs.

programmerta, 2025-01-11:
I just had to double check but the code does support two separate DPads on the MapleBus, and with multiple pins still available, it should be trivial to add it.

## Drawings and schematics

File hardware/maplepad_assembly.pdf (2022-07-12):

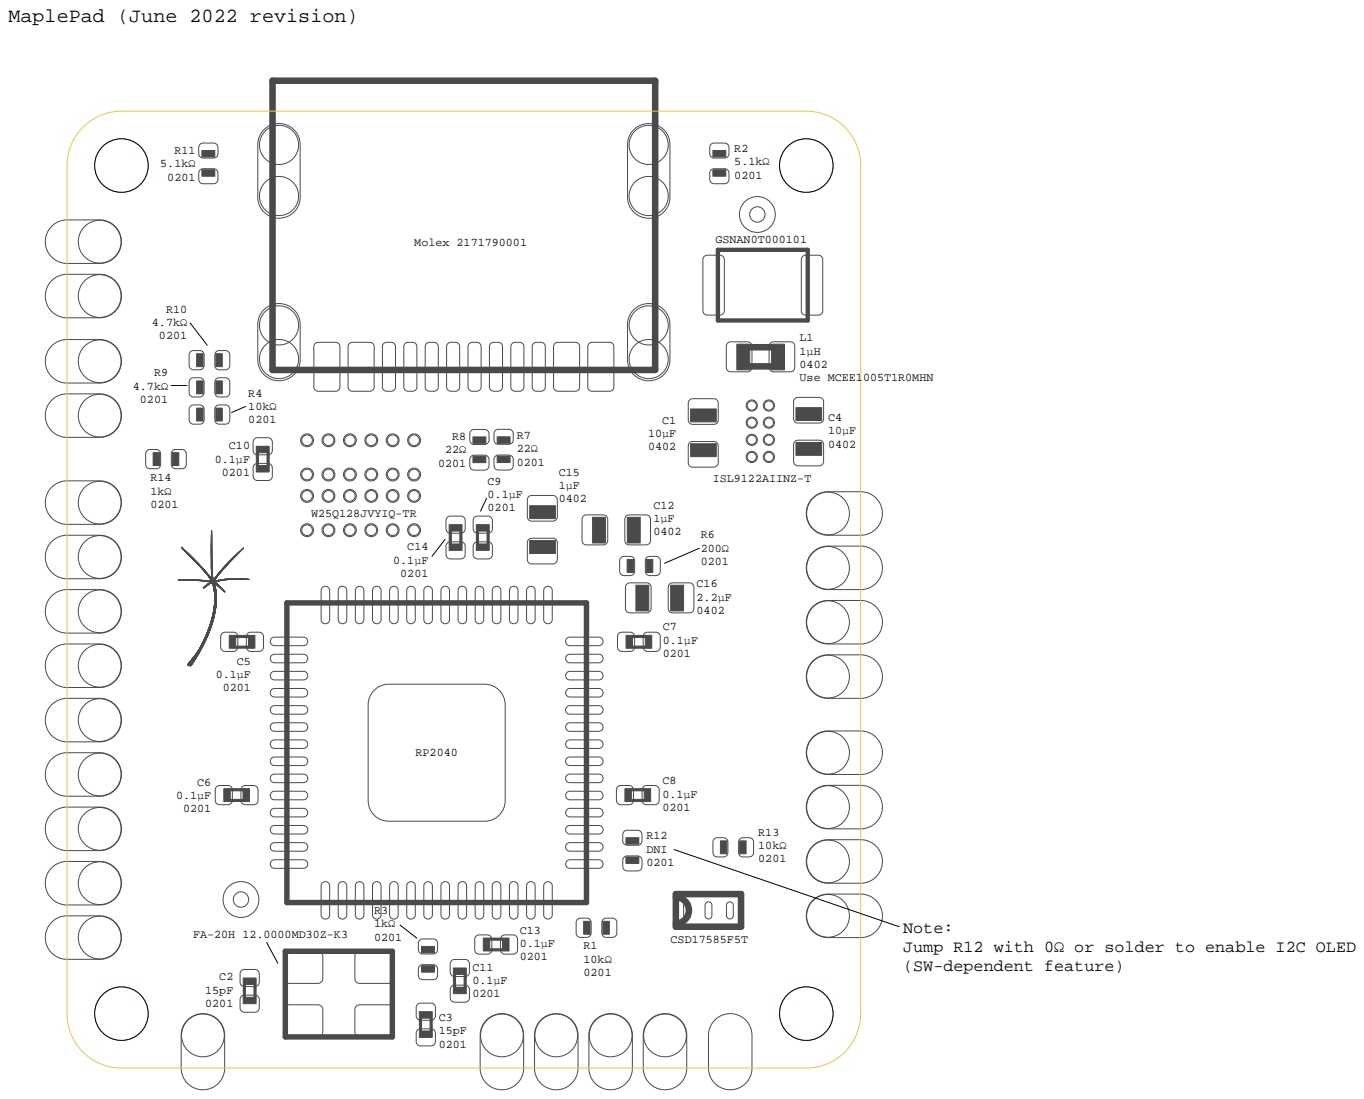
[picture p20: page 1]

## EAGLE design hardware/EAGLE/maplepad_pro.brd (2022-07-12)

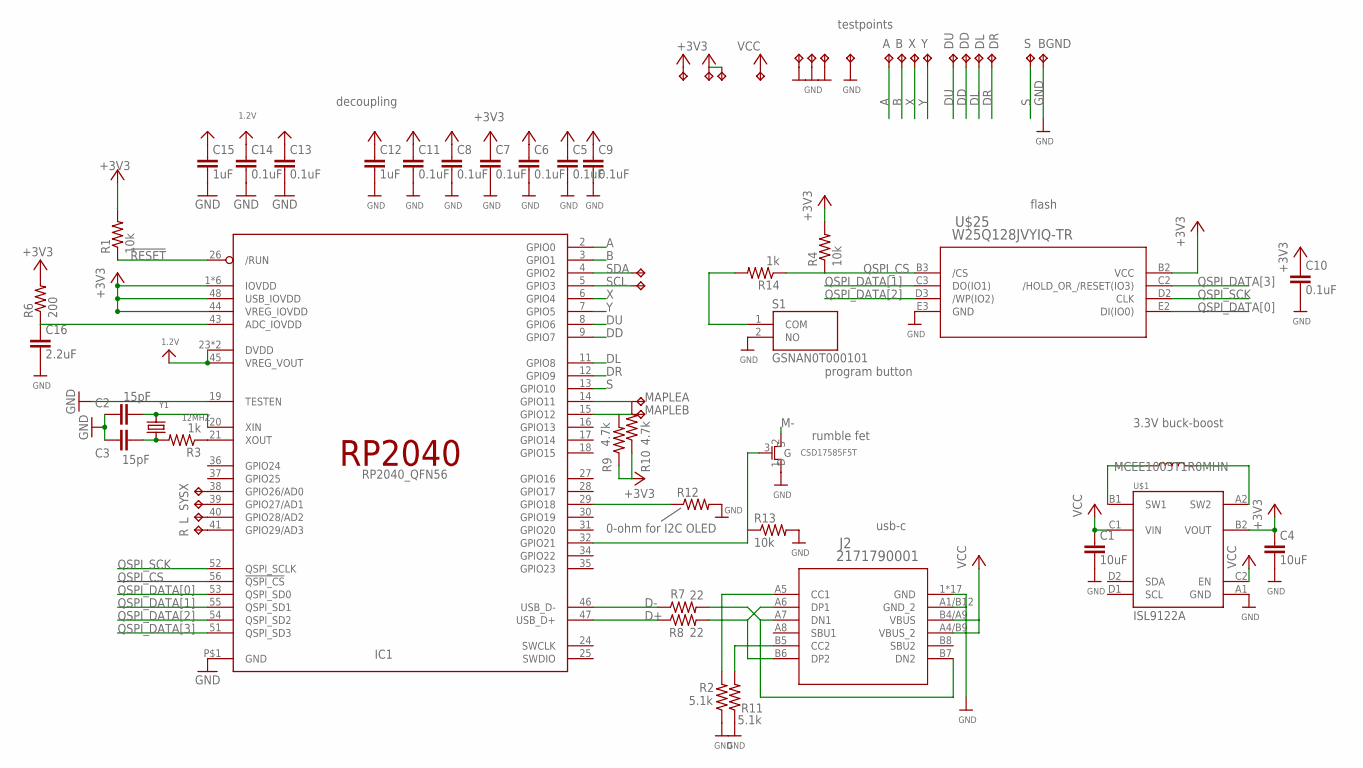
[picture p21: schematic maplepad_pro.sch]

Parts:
A, A0: TPTP10R; TP10R
B, B0: TPTP10R; TP10R
BGND: TPTP10R; TP10R
C1, C4: 10uF; C0402
C2, C3: 15pF; C0201
C5, C6, C7, C8, C9, C10, C11, C13, C14: 0.1uF; C0201
C12, C15: 1uF; C0402
C16: 2.2uF; C0402
DD: TPTP10R; TP10R
DL: TPTP10R; TP10R
DR: TPTP10R; TP10R
DU: TPTP10R; TP10R
IC1: RP2040_QFN56; QFN56_7MM_REDUCEDEPAD
J2: 2171790001; 2171790001_MOL
L: TPTP10R; TP10R
L2: MCEE1005T1R0MHN; R0402
LR3.1, LR3.3: TPTP10R; TP10R
LRGND, LRGND1: TPTP10R; TP10R
R: TPTP10R; TP10R
R1, R4, R13: 10k; R0201
R2, R11: 5.1k; R0201
R3, R14: 1k; R0201
R6: 200; R0201
R7, R8: 22; R0201
R9, R10: 4.7k; R0201
R12: 0-ohm for I2C OLED; R0201
S, S3.3: TPTP10R; TP10R
S1: GSNAN0T000101
SCL: TPTP10R; TP10R
SDA: TPTP10R; TP10R
SGND: TPTP10R; TP10R
SX: TPTP10R; TP10R
SY: TPTP10R; TP10R
U1: CSD17585F5T; YJK3_TEX
U$1: ISL9122A
U$25: W25Q128JVYIQ-TR; WLCSP24
V3.3: TPTP10R; TP10R
VGND: TPTP10R; TP10R
X: TPTP10R; TP10R
Y: TPTP10R; TP10R
Y1: 12MHZ; CRYSTAL_2.5X2

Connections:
1.2V: C13.1, C14.1, C15.1, IC1.23 (DVDD), IC1.45 (VREG_VOUT), IC1.50 (DVDD)
!RESET: IC1.26 (/RUN), R1.1
+3V3: C4.1, C5.1, C6.1, C7.1, C8.1, C9.1, C10.1, C11.1, C12.1, IC1.1 (IOVDD), IC1.10 (IOVDD), IC1.22 (IOVDD), IC1.33 (IOVDD), IC1.42 (IOVDD), IC1.44 (VREG_IOVDD), IC1.48 (USB_IOVDD), IC1.49 (IOVDD), LR3.3.TP, R1.2, R4.2, R6.2, R9.1, R10.1, S3.3.TP, U$1.B2 (VOUT), U$25.B2 (VCC), V3.3.TP
A: A.TP, IC1.2 (GPIO0)
B: B.TP, IC1.3 (GPIO1)
D+: IC1.47 (USB_D+), R8.1
D-: IC1.46 (USB_D-), R7.1
DD: DD.TP, IC1.9 (GPIO7)
DL: DL.TP, IC1.11 (GPIO8)
DR: DR.TP, IC1.12 (GPIO9)
DU: DU.TP, IC1.8 (GPIO6)
GND: BGND.TP, C1.2, C2.1, C3.1, C4.2, C5.2, C6.2, C7.2, C8.2, C9.2, C10.2, C11.2, C12.2, C13.2, C14.2, C15.2, C16.2, IC1.19 (TESTEN), IC1.P$1 (GND), J2.1 (GND), J2.2 (GND), J2.3 (GND), J2.4 (GND), J2.13 (GND), J2.14 (GND), J2.15 (GND), J2.16 (GND), J2.A1/B12 (GND_2), J2.B1/A12 (GND), J2.S_1_H1 (GND), J2.S_1_H2 (GND), J2.S_2_H1 (GND), J2.S_2_H2 (GND), J2.S_3_H1 (GND), J2.S_3_H2 (GND), J2.S_4_H1 (GND), J2.S_4_H2 (GND), LRGND.TP, LRGND1.TP, R2.1, R11.1, R12.2, R13.2, S1.2 (NO), SGND.TP, U1.1 (S), U$1.A1 (GND), U$25.E3 (GND), VGND.TP
M-: U1.2 (D)
MAPLEA: A0.TP, IC1.14 (GPIO11), R10.2
MAPLEB: B0.TP, IC1.15 (GPIO12), R9.2
unnamed: IC1.41 (GPIO29/AD3), R.TP
unnamed: IC1.40 (GPIO28/AD2), L.TP
unnamed: L2.1, U$1.B1 (SW1)
unnamed: L2.2, U$1.A2 (SW2)
unnamed: C2.2, IC1.20 (XIN), Y1.3 (2)
unnamed: C3.2, R3.2, Y1.1
unnamed: IC1.21 (XOUT), R3.1
unnamed: R14.2, S1.1 (COM)
unnamed: C16.1, IC1.43 (ADC_IOVDD), R6.1
unnamed: J2.A7 (DN1), J2.B7 (DN2), R7.2
unnamed: J2.A6 (DP1), J2.B6 (DP2), R8.2
unnamed: IC1.39 (GPIO27/AD1), SY.TP
unnamed: IC1.38 (GPIO26/AD0), SX.TP
unnamed: IC1.29 (GPIO18), R12.1
unnamed: J2.B5 (CC2), R11.2
unnamed: J2.A5 (CC1), R2.2
unnamed: IC1.32 (GPIO21), R13.1, U1.3 (G)
QSPI_CS: IC1.56 (!QSPI_CS), R4.1, R14.1, U$25.B3 (/CS)
QSPI_DATA[0]: IC1.53 (QSPI_SD0), U$25.E2 (DI(IO0))
QSPI_DATA[1]: IC1.55 (QSPI_SD1), U$25.C3 (DO(IO1))
QSPI_DATA[2]: IC1.54 (QSPI_SD2), U$25.D3 (/WP(IO2))
QSPI_DATA[3]: IC1.51 (QSPI_SD3), U$25.C2 (/HOLD_OR_/RESET(IO3))
QSPI_SCK: IC1.52 (QSPI_SCLK), U$25.D2 (CLK)
S: IC1.13 (GPIO10), S.TP
SCL: IC1.5 (GPIO3), SCL.TP
SDA: IC1.4 (GPIO2), SDA.TP
VCC: C1.1, J2.A4/B9 (VBUS_2), J2.B4/A9 (VBUS), LR3.1.TP, U$1.C1 (VIN), U$1.C2 (EN)
X: IC1.6 (GPIO4), X.TP
Y: IC1.7 (GPIO5), Y.TP

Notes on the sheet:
MCEE1005T1R0MHN
ISL9122A
3.3V buck-boost
flash
usb-c
rumble fet
testpoints
decoupling
program button

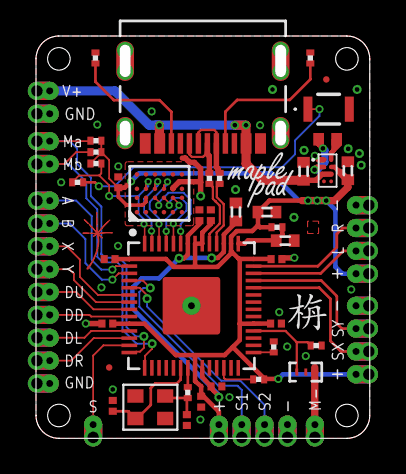
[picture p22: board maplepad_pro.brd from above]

Board: 2 copper layers, 18.5 x 22.4 mm, 63 parts (0 on the bottom side), 43 nets.

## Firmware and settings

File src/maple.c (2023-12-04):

/*
 * MaplePad
 * Dreamcast controller emulator for Raspberry Pi Pico (RP2040)
 * © Charlie Cole 2021
 *
 * Modified by Mackie Kannard-Smith (mackieks / YveltalGriffin) 2022
 * SSD1306 library by James Hughes (JamesH65)
 *
 * Check out the wiring diagram on Github! (https://github.com/mackieks/MaplePad)
 *
 * Maple TX done completely in PIO. Sends start of packet, data and end of
 * packet. Fed by DMA, so fire and forget.
 *
 * Maple RX done mostly in software on core 1. PIO just waits for transitions
 * and shifts in whenever data pins change. For maximum speed, the RX state
 * machine is implemented in lookup table to process 4 transitions at a time
 *
 */

#include "maple.h"
#include "menu.h"
#include "display.h"

// Maple Bus Defines and Funcs

#define SHOULD_SEND 1  // Set to zero to sniff two devices sending signals to each other
#define SHOULD_PRINT 0 // Nice for debugging but can cause timing issues

// Board Variant
#define PICO 1
#define MAPLEPAD 0

// HKT-7700 (Standard Controller) or HKT-7300 (Arcade Stick) (see maple.h)
#if HKT7700
#define NUM_BUTTONS 9
#elif HKT7300
#define NUM_BUTTONS 11
#endif

// Purupuru Enable
#define ENABLE_RUMBLE 1

// Memory Card
#define PHASE_SIZE (BLOCK_SIZE / 4)
#define FLASH_WRITE_DELAY 16      // About quarter of a second if polling once a frame
#define FLASH_OFFSET (128 * 1024) // How far into flash to store the memory card data. Check maplepad.bin for real code size

#if PICO
#define PAGE_BUTTON 21 // Pull GP21 low for Page Cycle. Avoid page cycling for ~10s after saving or copying VMU data to avoid data corruption
#elif MAPLEPAD
#define PAGE_BUTTON 20 // Dummy pin
#endif

#define PAGE_BUTTON_MASK 0x0608   // X, Y, and Start
#define PAGE_BACKWARD_MASK 0x0048 // Start and D-pad Left
#define PAGE_FORWARD_MASK 0x0088  // Start and D-pad Right

#define INPUT_ACT 20
#define OLED_PIN 22

#define MAPLE_A 11
#define MAPLE_B 12
#define PICO_PIN1_PIN_RX MAPLE_A
#define PICO_PIN5_PIN_RX MAPLE_B

#define ADDRESS_DREAMCAST 0
#define ADDRESS_CONTROLLER 0x20
#define ADDRESS_SUBPERIPHERAL0 0x01
#define ADDRESS_SUBPERIPHERAL1 0x02

// Checks flags and enables/disables subperipherals appropriately
// Probably a cleaner way to do this with a function called after menu(), but this is easy
#if ENABLE_RUMBLE
#define ADDRESS_CONTROLLER_AND_SUBS rumbleEnable ? vmuEnable ? (ADDRESS_CONTROLLER | ADDRESS_SUBPERIPHERAL0 | ADDRESS_SUBPERIPHERAL1) : (ADDRESS_CONTROLLER | ADDRESS_SUBPERIPHERAL1) : vmuEnable ? (ADDRESS_CONTROLLER | ADDRESS_SUBPERIPHERAL0) : (ADDRESS_CONTROLLER) // Determines which peripherals MaplePad reports
#else
#define ADDRESS_CONTROLLER_AND_SUBS vmuEnable ? (ADDRESS_CONTROLLER | ADDRESS_SUBPERIPHERAL0) : (ADDRESS_CONTROLLER)
#endif

#define ADDRESS_PORT_MASK 0xC0
#define ADDRESS_PERIPHERAL_MASK (~ADDRESS_PORT_MASK)

#define TXPIO pio0
#define RXPIO pio1

#define SWAP4(x)                                                                                                                                                                                                                                                                                                                                                                                                                                                                                                                                                                                                                                                                                                                                                                                                                                                                                                                                                                                                                       \
  do {                                                                                                                                                                                                                                                                                                                                                                                                                                                                                                                                                                                                                                                                                                                                                                                                                                                                                                                                                                                                                                 \
    x = __builtin_bswap32(x);                                                                                                                                                                                                                                                                                                                                                                                                                                                                                                                                                                                                                                                                                                                                                                                                                                                                                                                                                                                                          \
  } while (0)

#define LCD_Width 48
#define LCD_Height 32
#define LCD_NumCols 6          // 48 / 8
#define LCDFramebufferSize 192 // (48 * 32) / 8
#define BPPacket 192           // Bytes Per Packet

const uint16_t color = 0xffff;

volatile uint16_t palette[] = {
    0xf800, // red
    0xfba0, // orange
    0xff80, // yellow
    0x7f80, // yellow-green
    0x0500, // green
    0x045f, // blue
    0x781f, // violet
    0x780d  // magenta
};

typedef enum ESendState_e {
  SEND_NOTHING,
  SEND_CONTROLLER_INFO,
  SEND_CONTROLLER_ALL_INFO,
  SEND_CONTROLLER_STATUS,
  SEND_PURUPURU_STATUS,
  SEND_VMU_INFO,
  SEND_VMU_ALL_INFO,
  SEND_MEMORY_INFO,
  SEND_LCD_INFO,
  SEND_PURUPURU_INFO,
  SEND_PURUPURU_ALL_INFO,
  SEND_PURUPURU_MEDIA_INFO,
  SEND_ACK,
  SEND_DATA,
  SEND_PURUPURU_DATA,
  SEND_TIMER_DATA,
  SEND_PURUPURU_CONDITION,
  SEND_TIMER_CONDITION //
} ESendState;

enum ECommands {
  CMD_RESPOND_FILE_ERROR = -5,
  CMD_RESPOND_SEND_AGAIN = -4,
  CMD_RESPOND_UNKNOWN_COMMAND = -3,
  CMD_RESPOND_FUNC_CODE_UNSUPPORTED = -2,
  CMD_NO_RESPONSE = -1,
  CMD_DEVICE_REQUEST = 1,
  CMD_ALL_STATUS_REQUEST,
  CMD_RESET_DEVICE,
  CMD_SHUTDOWN_DEVICE,
  CMD_RESPOND_DEVICE_STATUS,
  CMD_RESPOND_ALL_DEVICE_STATUS,
  CMD_RESPOND_COMMAND_ACK,
  CMD_RESPOND_DATA_TRANSFER,
  CMD_GET_CONDITION,
  CMD_GET_MEDIA_INFO,
  CMD_BLOCK_READ,
  CMD_BLOCK_WRITE,
  CMD_BLOCK_COMPLETE_WRITE,
  CMD_SET_CONDITION //
};

enum EFunction {
  FUNC_CONTROLLER = 1,  // FT0
  FUNC_MEMORY_CARD = 2, // FT1
  FUNC_LCD = 4,         // FT2
  FUNC_TIMER = 8,       // FT3
  FUNC_VIBRATION = 256  // FT8
};

// Buffers
static uint8_t RecieveBuffer[4096] __attribute__((aligned(4))); // Ring buffer for reading packets
static uint8_t Packet[1024 + 8] __attribute__((aligned(4)));    // Temp buffer for consuming packets (could remove)

static FControllerPacket ControllerPacket;                  // Send buffer for controller status packet (pre-built for speed)
static FInfoPacket InfoPacket;                              // Send buffer for controller info packet (pre-built for speed)
static FInfoPacket SubPeripheral0InfoPacket;                // Send buffer for memory card info packet (pre-built for speed)
static FInfoPacket SubPeripheral1InfoPacket;                // Send buffer for memory card info packet (pre-built for speed)
static FAllInfoPacket AllInfoPacket;                        // Send buffer for controller info packet (pre-built for speed)
static FAllInfoPacket SubPeripheral0AllInfoPacket;          // Send buffer for memory card info packet (pre-built for speed)
static FAllInfoPacket SubPeripheral1AllInfoPacket;          // Send buffer for memory card info packet (pre-built for speed)
static FMemoryInfoPacket MemoryInfoPacket;                  // Send buffer for memory card info packet (pre-built for speed)
static FLCDInfoPacket LCDInfoPacket;                        // Send buffer for LCD info packet (pre-built for speed)
static FPuruPuruInfoPacket PuruPuruInfoPacket;              // Send buffer for PuruPuru info packet (pre-built for speed)
static FPuruPuruConditionPacket PuruPuruConditionPacket;    // Send buffer for PuruPuru condition packet (pre-built for speed)
static FTimerConditionPacket TimerConditionPacket;          // Send buffer for timer condition packet (pre-built for speed)
static FACKPacket ACKPacket;                                // Send buffer for ACK packet (pre-built for speed)
static FBlockReadResponsePacket DataPacket;                 // Send buffer for Data packet (pre-built for speed)
static FPuruPuruBlockReadResponsePacket PuruPuruDataPacket; // Send buffer for PuruPuru packet (pre-built for speed)
static FTimerBlockReadResponsePacket TimerDataPacket;       // Send buffer for PuruPuru packet (pre-built for speed)

static ESendState NextPacketSend = SEND_NOTHING;
static uint OriginalControllerCRC = 0;
static uint OriginalMemCardReadBlockResponseCRC = 0;
static uint OriginalPuruPuruReadBlockResponseCRC = 0;
static uint OriginalTimerReadBlockResponseCRC = 0;
static uint TXDMAChannel = 0;

// Controller
volatile bool inputActive = false;

// Memory Card
static uint8_t MemoryCard[128 * 1024];
static uint SectorDirty = 0;
static uint SendBlockAddress = ~0u;
static uint MessagesSinceWrite = FLASH_WRITE_DELAY;
volatile bool PageCycle = false;
volatile bool VMUCycle = false;
static uint8_t VMUCycleCount = 0;
static uint32_t lastPress = 0;
volatile bool inputFlag = 0;
volatile uint64_t lastInput = 0;

// LCD
static const uint8_t NumWrites = LCDFramebufferSize / BPPacket;
static uint8_t LCDFramebuffer[LCDFramebufferSize] = {0};
volatile bool LCDUpdated = false;
volatile bool endSplash = true;

// Timer
static uint8_t dateTime[8] = {0};

// Purupuru
static bool purupuruUpdated = false;
static uint32_t prevpurupuru_cond = 0;
static uint32_t purupuru_cond = 0;
static uint8_t ctrl = 0;
static uint8_t power = 0;
static uint8_t freq = 0;
static uint8_t inc = 0;

static uint32_t vibeFreqCount = 0;

static uint8_t AST[80] = {0}; // Vibration auto-stop time setting. Default is 5s
static uint32_t AST_timestamp = 0;

uint8_t map(uint8_t x, uint8_t in_min, uint8_t in_max, uint8_t out_min, uint8_t out_max) {

  if (x < in_min)
    return out_min;
  else if (x > in_max)
    return out_max;
  else
    return (x - in_min) * (out_max - out_min) / (in_max - in_min) + out_min;
}

uint32_t map_uint32(uint32_t x, uint32_t in_min, uint32_t in_max, uint32_t out_min, uint32_t out_max) {
  if (x < in_min)
    return out_min;
  else if (x > in_max)
    return out_max;
  else
    return (x - in_min) * (out_max - out_min) / (in_max - in_min) + out_min;
}

uint8_t min(uint8_t x, uint8_t y) { return x <= y ? x : y; }

uint8_t max(uint8_t x, uint8_t y) { return x >= y ? x : y; }

uint8_t flashData[64] = {0}; // Persistent data (stick/trigger calibration, flags. See menu.h) Lives at FLASH_OFFSET * 9

void softResetHandler() {
  if (gpio_get_irq_event_mask(INPUT_ACT) & GPIO_IRQ_EDGE_FALL) {
    
    gpio_acknowledge_irq(INPUT_ACT, GPIO_IRQ_EDGE_FALL);
    gpio_set_dir(INPUT_ACT, GPIO_IN); // deassert input_act pin

    lastInput = to_us_since_boot(get_absolute_time());

  }
}

void readFlash() {
  memset(MemoryCard, 0, sizeof(MemoryCard));
  memcpy(MemoryCard, (uint8_t *)XIP_BASE + (FLASH_OFFSET * currentPage),
         sizeof(MemoryCard)); // read into variable
  SectorDirty = CheckFormatted(MemoryCard, currentPage);
}

void updateFlashData() // Update calibration data and flags
{
  uint Interrupt = save_and_disable_interrupts();
  flash_range_erase((FLASH_OFFSET * 9), FLASH_SECTOR_SIZE);
  flash_range_program((FLASH_OFFSET * 9), (uint8_t *)flashData, FLASH_PAGE_SIZE);
  restore_interrupts(Interrupt);
}

uint CalcCRC(const uint *Words, uint NumWords) {
  uint XOR_Checksum = 0;
  for (uint i = 0; i < NumWords; i++) {
    XOR_Checksum ^= *(Words++);
  }
  XOR_Checksum ^= (XOR_Checksum << 16);
  XOR_Checksum ^= (XOR_Checksum << 8);
  return XOR_Checksum;
}

void BuildACKPacket() {
  ACKPacket.BitPairsMinus1 = (sizeof(ACKPacket) - 7) * 4 - 1;

  ACKPacket.Header.Command = CMD_RESPOND_COMMAND_ACK;
  ACKPacket.Header.Destination = ADDRESS_DREAMCAST;
  ACKPacket.Header.Origin = ADDRESS_CONTROLLER;
  ACKPacket.Header.NumWords = 0;

  ACKPacket.CRC = CalcCRC((uint *)&ACKPacket.Header, sizeof(ACKPacket) / sizeof(uint) - 2);
}

void BuildInfoPacket() {
  InfoPacket.BitPairsMinus1 = (sizeof(InfoPacket) - 7) * 4 - 1;

  InfoPacket.Header.Command = CMD_RESPOND_DEVICE_STATUS;
  InfoPacket.Header.Destination = ADDRESS_DREAMCAST;
  InfoPacket.Header.Origin = ADDRESS_CONTROLLER_AND_SUBS;
  InfoPacket.Header.NumWords = sizeof(InfoPacket.Info) / sizeof(uint);
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
int main() {
  // stdio_init_all();
  // set_sys_clock_khz(175000, false); // Overclock seems to lead to instability

  adc_init();
  adc_set_clkdiv(0);
  adc_gpio_init(26); // Stick X
  adc_gpio_init(27); // Stick Y
  adc_gpio_init(28); // Left Trigger
  adc_gpio_init(29); // Right Trigger

  gpio_init(25);
  gpio_set_dir(25, GPIO_OUT);
  gpio_put(25, 0);

  // sleep_ms(150); // wait for power to stabilize

  memset(flashData, 0, sizeof(flashData));
  memcpy(flashData, (uint8_t *)XIP_BASE + (FLASH_OFFSET * 9), sizeof(flashData)); // read into variable

  // Input activity pin (faux open drain)
  gpio_init(INPUT_ACT);
  gpio_disable_pulls(INPUT_ACT);
  gpio_pull_up(INPUT_ACT);
  gpio_set_dir(INPUT_ACT, GPIO_OUT);
  gpio_put(INPUT_ACT, 0);
  gpio_set_dir(INPUT_ACT, GPIO_IN);

    // Pre-format VMU pages since rumble timer interrupt interferes with on-the-fly formatting
  if (firstBoot || version != CURRENT_FW_VERSION) { // flash is 0xFF when erased! also run if FW version is different (post-update)
    uint Interrupts = save_and_disable_interrupts();

    for (int page = 1; page <= 8; page++) {
      currentPage = page;

      readFlash(); // includes checkFormatted

      while (SectorDirty) {
        uint Sector = 31 - __builtin_clz(SectorDirty);
        SectorDirty &= ~(1 << Sector);
        uint SectorOffset = Sector * FLASH_SECTOR_SIZE;

        flash_range_erase((FLASH_OFFSET * currentPage) + SectorOffset, FLASH_SECTOR_SIZE);
        flash_range_program((FLASH_OFFSET * currentPage) + SectorOffset, &MemoryCard[SectorOffset], FLASH_SECTOR_SIZE);
      }
    }
    restore_interrupts(Interrupts);
    currentPage = 1;

    // Also set up some reasonable analog stick, trigger and flag defaults
    xMin = 0x00;
    xCenter = 0x80;
    xMax = 0xff;
    xDeadzone = 0x0f;
    xAntiDeadzone = 0x04;
    invertX = 0;

    yMin = 0x00;
    yCenter = 0x00;
    yMax = 0xff;
    yDeadzone = 0x0f;
    yAntiDeadzone = 0x04;
    invertY = 0;

    lMin = 0x00;
    lMax = 0xff;
    lDeadzone = 0x00;
    lAntiDeadzone = 0x04;
    invertL = 0;

    rMin = 0x00;
    rMax = 0xff;
    rDeadzone = 0x00;
    rAntiDeadzone = 0x04;
    invertR = 0;

    oledFlip = 0;
    swapXY = 0;
    swapLR = 0;
    autoResetEnable = 0;
    autoResetTimer = 0x5A; // 180s
    version = CURRENT_FW_VERSION;

    firstBoot = 0; // first boot setup done

    updateFlashData();    
  }

  // OLED Select GPIO (high/open = SSD1331, Low = SSD1306)
  gpio_init(OLED_PIN);
  gpio_set_dir(OLED_PIN, GPIO_IN);
  gpio_pull_up(OLED_PIN);

  sleep_ms(20);

  // TO-DO: Update with 0, 1, 2 once new AMOLED is working
  // volatile uint8_t oledSel = gpio_get(OLED_PIN);
  oledType = gpio_get(OLED_PIN);
  updateFlashData();

  if (oledType) { // set up SPI for SSD1331 OLED
    spi_init(SSD1331_SPI, SSD1331_SPEED);
    spi_set_format(spi0, 8, SPI_CPOL_1, SPI_CPHA_1, SPI_MSB_FIRST);
    gpio_set_function(SCK, GPIO_FUNC_SPI);
    gpio_set_function(MOSI, GPIO_FUNC_SPI);

    ssd1331_init();
    splashSSD1331(); // n.b. splashSSD1331 configures DMA channel!
  } else {           // set up I2C for SSD1306 OLED
    i2c_init(SSD1306_I2C, I2C_CLOCK * 1000);
    gpio_set_function(I2C_SDA, GPIO_FUNC_I2C);
    gpio_set_function(I2C_SCL, GPIO_FUNC_I2C);
    gpio_pull_up(I2C_SDA);
    gpio_pull_up(I2C_SCL);

    ssd1306_init();
    splashSSD1306();
  }

#if ENABLE_RUMBLE
  // PWM setup for rumble
  gpio_init(15);
  gpio_set_function(15, GPIO_FUNC_PWM);
  gpio_disable_pulls(15);
  gpio_set_drive_strength(15, GPIO_DRIVE_STRENGTH_12MA);
  gpio_set_slew_rate(15, GPIO_SLEW_RATE_FAST);
  uint slice_num = pwm_gpio_to_slice_num(15);

  pwm_config config = pwm_get_default_config();
  pwm_config_set_clkdiv(&config, 16.f);
  pwm_init(slice_num, &config, true);
  pwm_set_gpio_level(15, 0);

  struct repeating_timer timer;
  // negative interval means the callback function is called every 500us regardless of how long callback takes to execute
  add_repeating_timer_us(-500, vibeHandler, NULL, &timer);
#endif

  // Page cycle interrupt
  gpio_init(PAGE_BUTTON);
  gpio_set_dir(PAGE_BUTTON, GPIO_IN);
  gpio_pull_up(PAGE_BUTTON);
  gpio_set_irq_enabled(PAGE_BUTTON, GPIO_IRQ_EDGE_FALL, true); 
  gpio_add_raw_irq_handler(PAGE_BUTTON, pageToggle);
  irq_set_enabled(IO_IRQ_BANK0, true); // enable all gpio interrupts (pagetoggle and input_act)

  lastPress = to_ms_since_boot(get_absolute_time());

  SetupButtons();

  if (!gpio_get(ButtonInfos[3].InputIO) && !gpio_get(ButtonInfos[8].InputIO)) { // Y + Start
    runMenu();
    updateFlashData();
    clearDisplay();
    updateDisplay();
  }

  // Read current VMU into memory
  if(vmuEnable) readFlash();

  if(autoResetEnable){
    gpio_set_irq_enabled(INPUT_ACT, GPIO_IRQ_EDGE_FALL, true);
    gpio_add_raw_irq_handler(INPUT_ACT, softResetHandler);
  }

  // Start Core1 Maple RX
  multicore_launch_core1(core1_entry);

  // Controller packets
  BuildInfoPacket();
  BuildAllInfoPacket();
  BuildControllerPacket();

  // Subperipheral packets
  BuildACKPacket();
  BuildSubPeripheral0InfoPacket();
  BuildSubPeripheral0AllInfoPacket();
  BuildSubPeripheral1InfoPacket();
  BuildSubPeripheral1AllInfoPacket();
  BuildMemoryInfoPacket();
  BuildLCDInfoPacket();
  BuildPuruPuruInfoPacket();
  BuildDataPacket();

  SetupMapleTX();
  SetupMapleRX();

  uint StartOfPacket = 0;
  while (true) {
    uint EndOfPacket = multicore_fifo_pop_blocking();

    // TODO: Improve. Would be nice not to move here
    for (uint i = StartOfPacket; i < EndOfPacket; i += 4) {
      *(uint *)&Packet[i - StartOfPacket] = __builtin_bswap32(*(uint *)&RecieveBuffer[i & (sizeof(RecieveBuffer) - 1)]);
    }

    uint PacketSize = EndOfPacket - StartOfPacket;
    ConsumePacket(PacketSize);
    StartOfPacket = ((EndOfPacket + 3) & ~3);

    if (NextPacketSend != SEND_NOTHING) {
#if SHOULD_SEND
      if (!dma_channel_is_busy(TXDMAChannel)) {
        switch (NextPacketSend) {
        case SEND_CONTROLLER_INFO:
          SendPacket((uint *)&InfoPacket, sizeof(InfoPacket) / sizeof(uint));
          break;
        case SEND_CONTROLLER_ALL_INFO:
          SendPacket((uint *)&AllInfoPacket, sizeof(AllInfoPacket) / sizeof(uint));
          break;
        case SEND_CONTROLLER_STATUS:
          if (VMUCycle) {
            if (VMUCycleCount < 5) {
              ControllerPacket.Header.Origin = ADDRESS_CONTROLLER;
              VMUCycleCount++;
            } else {
              VMUCycleCount = 0;
              VMUCycle = false;
            }
          } else {
            ControllerPacket.Header.Origin = ADDRESS_CONTROLLER_AND_SUBS;
          }
          SendControllerStatus();

          // Doing flash writes on controller status as likely got a frame
          // until next message and unlikely to be in middle of doing rapid
          // flash operations like a format or reading a large file. Ideally
          // this would be asynchronous but doesn't seem possible :( We delay
          // writes as flash reprogramming too slow to keep up with Dreamcast.
          // Also has side benefit of amalgamating flash writes thus reducing
          // wear.
          if (SectorDirty && !multicore_fifo_rvalid() && MessagesSinceWrite >= FLASH_WRITE_DELAY) {
            uint Sector = 31 - __builtin_clz(SectorDirty);
            SectorDirty &= ~(1 << Sector);
            uint SectorOffset = Sector * FLASH_SECTOR_SIZE;

            uint Interrupts = save_and_disable_interrupts();
            flash_range_erase((FLASH_OFFSET * currentPage) + SectorOffset, FLASH_SECTOR_SIZE);
            flash_range_program((FLASH_OFFSET * currentPage) + SectorOffset, &MemoryCard[SectorOffset], FLASH_SECTOR_SIZE);
            restore_interrupts(Interrupts);
          } else if (!SectorDirty && MessagesSinceWrite >= FLASH_WRITE_DELAY && PageCycle) {
            readFlash();
            PageCycle = false;
            VMUCycle = true;
          } else if (MessagesSinceWrite < FLASH_WRITE_DELAY) {
            MessagesSinceWrite++;
          }
          if (LCDUpdated) {
            if (!oledType && endSplash){ // clear SSD1306 128x64 splashscreen
              clearDisplay();
              endSplash = false;
            }
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

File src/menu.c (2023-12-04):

/*
 * MaplePad Menu
 *
 * Attempt at a flexible & extensible hierarchical menu system
 *
 * TO-DO:
 * ☐ VMU Palette submenu
 * ☐ UI Palette submenu
 * ☐ Deadzone adjust submenus for stick + trigger
 * ☐ Button test submenu (lineart + ellipse routine for now)
 * ☐ OLED Detect (ssd1331present, needs to make certain menu items invisible if ssd1306 is selected)
 *
 */

#include "maple.h"
#include "menu.h"
#include "display.h"

uint32_t flipLockout;
volatile bool redraw = 1;

struct repeating_timer redrawTimer;

static uint16_t color = 0x0000;

int paletteVMU(menu *self) {
  // draw VMU palette selection
  return (1);
}

int paletteUI(menu *self) {
  // draw UI palette selection
  return (1);
}

int buttontest(menu *self) {
  // draw button test
  return (1);
}

int sCal(menu *self) {
  // draw stick calibration
  redraw = 0; // Disable redrawMenu

  while (!gpio_get(ButtonInfos[0].InputIO));

  clearDisplay();
  char *cal_string = "Center stick,";
  putString(cal_string, 0, 0, color);
  cal_string = "then press A!";
  putString(cal_string, 0, 1, color);
  updateDisplay();

  sleep_ms(50);
  while (gpio_get(ButtonInfos[0].InputIO));

  adc_select_input(0); // X
  xCenter = adc_read() >> 4;

  adc_select_input(1); // Y
  yCenter = adc_read() >> 4;

  clearDisplay();
  cal_string = "Move stick";
  putString(cal_string, 0, 0, color);
  cal_string = "  around";
  putString(cal_string, 0, 1, color);
  cal_string = "  a lot!";
  putString(cal_string, 0, 2, color);
  updateDisplay();

  xMin = 0x80;
  xMax = 0x80;
  yMin = 0x80;
  yMax = 0x80;

  uint32_t start = to_ms_since_boot(get_absolute_time());
  while ((to_ms_since_boot(get_absolute_time()) - start) < 4000 ? true : gpio_get(ButtonInfos[0].InputIO)) {
    static bool prompt = true;
    static uint8_t xData = 0;
    static uint8_t yData = 0;

    adc_select_input(0); // X
    xData = adc_read() >> 4;

    adc_select_input(1); // Y
    yData = adc_read() >> 4;

    if (xData < xMin)
      xMin = xData;
    else if (xData > xMax)
      xMax = xData;

    if (yData < yMin)
      yMin = yData;
    else if (yData > yMax)
      yMax = yData;

    // printf("\033[H\033[2J");
    // printf("\033[36m");
    // printf("xRaw: 0x%04x  yRaw: 0x%02x\n", xRaw, yRaw);
    // printf("xData: 0x%02x  yData: 0x%02x\n", xData, yData);
    // printf("xMin: 0x%02x  xMax: 0x%02x yMin: 0x%02x yMax: 0x%02x\n", xMin, xMax, yMin, yMax);
    // sleep_ms(50);

    if ((to_ms_since_boot(get_absolute_time()) - start) >= 4000 && prompt) {
      prompt = false;
      cal_string = "  Press A";
      putString(cal_string, 0, 3, color);
      cal_string = " when done!";
      putString(cal_string, 0, 4, color);
      updateDisplay();
    }
  }

  // Write config values to flash
  updateFlashData();

  redraw = 1;

  return (1);
}

int tCal(menu *self) {
  // draw trigger calibration
  redraw = 0; // Disable redrawMenu

  while (!gpio_get(ButtonInfos[0].InputIO))
    ;

  clearDisplay();
  char *cal_string = "leave";
  putString(cal_string, 0, 0, color);
  cal_string = "triggers idle";
  putString(cal_string, 0, 1, color);
  cal_string = "and press A";
  putString(cal_string, 0, 2, color);
  updateDisplay();

  sleep_ms(500);
  while (gpio_get(ButtonInfos[0].InputIO))
    ;

  adc_select_input(2); // L
  lMin = adc_read() >> 4;

  adc_select_input(3); // R
  rMin = adc_read() >> 4;

  clearDisplay();
  cal_string = "hold lMax";
  putString(cal_string, 0, 0, color);
  cal_string = "and press A";
  putString(cal_string, 0, 1, color);
  updateDisplay();

  sleep_ms(500);
  while (gpio_get(ButtonInfos[0].InputIO))
    ;

  adc_select_input(2); // lMax
  lMax = adc_read() >> 4;

  clearDisplay();
  cal_string = "hold rMax";
  putString(cal_string, 0, 0, color);
  cal_string = "and press A";
  putString(cal_string, 0, 1, color);
  updateDisplay();

  sleep_ms(500);
  while (gpio_get(ButtonInfos[0].InputIO))
    ;

  adc_select_input(3); // rMax
  rMax = adc_read() >> 4;

  if (lMin > lMax) {
    uint temp = lMin;
    lMin = lMax;
    lMax = temp;
  }

  if (rMin > rMax) {
    uint temp = rMin;
    rMin = rMax;
    rMax = temp;
  }

  // Write config values to flash
  updateFlashData();

  redraw = 1;

  return (1);
}

int sDeadzone(menu *self) {
  // draw deadzone configuration

  redraw = 0;

  char* cal_string = "X Deadzone";
  char sdata[5] = {0};

  while(!gpio_get(ButtonInfos[0].InputIO));

  while (gpio_get(ButtonInfos[0].InputIO)) {
    clearDisplay();
    putString(cal_string, 0, 0, color);
    sprintf(sdata, "0x%02x", xDeadzone);
    putString(sdata, 3, 2, color);
    updateDisplay();

    if (!gpio_get(ButtonInfos[4].InputIO)){
      if (xDeadzone < 128)
        xDeadzone++;}
    else if (!gpio_get(ButtonInfos[5].InputIO)){
      if (xDeadzone > 0)
        xDeadzone--;}
    else if (!gpio_get(ButtonInfos[6].InputIO)){
      if (xDeadzone > 7)
        xDeadzone = xDeadzone - 8;}
    else if (!gpio_get(ButtonInfos[7].InputIO)){
      if (xDeadzone < 121)
        xDeadzone = xDeadzone + 8;}

    sleep_ms(60);
  }

  while(!gpio_get(ButtonInfos[0].InputIO));

  while (gpio_get(ButtonInfos[0].InputIO)) {
    clearDisplay();
    cal_string = "X";
    putString(cal_string, 5, 0, color);
    cal_string = "AntiDeadzone";
    putString(cal_string, 0, 1, color);
    sprintf(sdata, "0x%02x", xAntiDeadzone);
    putString(sdata, 3, 3, color);
    updateDisplay();

    if (!gpio_get(ButtonInfos[4].InputIO)){
      if (xAntiDeadzone < 128)
        xAntiDeadzone++;}
    else if (!gpio_get(ButtonInfos[5].InputIO)){
      if (xAntiDeadzone > 0)
        xAntiDeadzone--;}
    else if (!gpio_get(ButtonInfos[6].InputIO)){
      if (xAntiDeadzone > 7)
        xAntiDeadzone = xAntiDeadzone - 8;}
    else if (!gpio_get(ButtonInfos[7].InputIO)){
      if (xAntiDeadzone < 121)
        xAntiDeadzone = xAntiDeadzone + 8;}

    sleep_ms(60);
  }

  while(!gpio_get(ButtonInfos[0].InputIO));

  while (gpio_get(ButtonInfos[0].InputIO)) {
    clearDisplay();
    cal_string = "Y Deadzone";
    putString(cal_string, 0, 0, color);
    sprintf(sdata, "0x%02x", yDeadzone);
    putString(sdata, 3, 2, color);
    updateDisplay();

    if (!gpio_get(ButtonInfos[4].InputIO)){
      if (yDeadzone < 128)
        yDeadzone++;}
    else if (!gpio_get(ButtonInfos[5].InputIO)){
      if (yDeadzone > 0)
        yDeadzone--;}
    else if (!gpio_get(ButtonInfos[6].InputIO)){
      if (yDeadzone > 7)
        yDeadzone = yDeadzone - 8;}
    else if (!gpio_get(ButtonInfos[7].InputIO)){
      if (yDeadzone < 121)
        yDeadzone = yDeadzone + 8;}

    sleep_ms(60);
  }

  while(!gpio_get(ButtonInfos[0].InputIO));

  while (gpio_get(ButtonInfos[0].InputIO)) {
    clearDisplay();
    cal_string = "Y";
    putString(cal_string, 5, 0, color);
    cal_string = "AntiDeadzone";
    putString(cal_string, 0, 1, color);
    sprintf(sdata, "0x%02x", yAntiDeadzone);
    putString(sdata, 3, 3, color);
    updateDisplay();
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

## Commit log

2021-02-07 Buttons and LEDs but bad packets are back
2021-02-13 Some fast recieve bug fixing
    [maple.c]
2021-02-14 Added photos and design files
    [CorkBottom.dxf, PopnMusic9 v31.f3d, PopnMusic9Bottom2.dxf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]
2021-03-06 First attempt at controller board that fits in PCB slot
    [DriverBoard.kicad_pcb, DriverBoard.sch]
2021-03-06 Added 5V LED drivers
    [DriverBoard-B_Cu.gbr, DriverBoard-B_Mask.gbr, DriverBoard-B_SilkS.gbr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]
2021-03-20 Switched misleading silkscreen and updated part numbers
    [DriverBoard-B_Cu.gbr, DriverBoard-B_Mask.gbr, DriverBoard-B_SilkS.gbr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]
2021-03-20 Added some info about PCB
2021-08-30 FT2: I2C LCD
    Added:
    -Monochrome LCD (FT2) with SSD1306 128*64 I2C OLED for VMU display
    -Analog Triggers
    -Basic Timer (FT3) reporting; Timer packets not yet implemented
    [CorkBottom.dxf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]
2021-09-04 MaplePad Hardware Update
    -Updated pin assignments in maple.c for MaplePad
    -Gerbers and BOM for MaplePad PCB added
    -Preliminary dual subperipheral support added
    -Preliminary FT8 (vibration) packet format
    [maple.c]
2021-09-05 Multipaging Update
    -Added multipaging to FT1 Storage functionality
    -8 separate 200-block memory cards
    -Interrupt-driven page cycling using pushbutton
    Misc:
    -Toned down overclock to mitigate instability (now 200MHz)
2021-09-05 Page Button Fix
    -Added 750ms page cycle debounce delay
    -Initial support for 128*64 OLED testing
    [maple.c]
2021-11-20 spi color oled in progress
2021-11-21 Custom palettes for SPI OLED
2022-02-01 WIP Rumble Implementation
    -Purupuru functionality (WIP)
    -Color SPI OLED tweaks
    ...and probably more I've forgotten!
2022-07-12 Add MaplePad PCB image
2022-07-12 MaplePad HW Files
    -EAGLE schematic and board
    -Gerbers
    -BOM
    -Assembly drawing
    [maplepad_pro.brd, maplepad_pro.sch]
2022-07-12 Update HW stuff
    [maplepad_pro.brd, maplepad_pro.sch]
2022-07-15 working on Pico/MaplePad support
2022-07-31 PuruPuru and FT2 DMA Update
    Massive update:
    -Vibration handling is almost feature-complete, including incrementing pulses, convergent and divergent vibration, and auto-stop time framework.
    -SSD1331 OLED now uses DMA instead of blocking SPI
    -Optional button combo (X + Y + Start) to activate VMU page cycle
    -Tweaks to rumble GPIO settings
    [maple.c, ssd1331.h]
2022-08-08 VMU improvements, rumble fixes, bug squashin'
    -Filesystem tweaks to increase data area to 238 blocks per page
    -Rate-limited button combo VMU page cycling
    -Fixed vibeHandler timer settings to improve accuracy
    -Fixed incorrect handling of Purupuru commands when vibePower = 0
    -Increased flash_write_delay to improve reliability
    -Custom palettes in Dreamcast BIOS for memory cards
    -New custom VMU icons (both monochrome label icon for OLED and color Volume Icon for BIOS)
    [maple.c]
2022-08-15 Packet format updates
    Various bugfixes for issues found while troubleshooting Sega Rally 2, mostly packet formatting stuff
    Revert to 200 block memcards to avoid issues when copying in BIOS
    [maple.c]
2022-08-18 FT3 Timer Initial Support
    ft3 data structures, command handling, block_read bugfixes
    [maple.c, menu.c, menu.h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]
2022-09-19 Menu updates, packet data fixes, cleanup
    [maple.c, menu.c, menu.h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]
2022-09-30 added wiring diagram!
2022-10-16 Fix Extended Device Info fields
    -fixed arcade stick free device status
    -fixed arcade stick power consumption
    -updated standard controller free device status to more recent HKT-7700 revision
    [maple.c]
2022-10-20 oledType fixes
    mono OLED fixes (WIP)
    [maple.c, menu.c, menu.h]
2022-10-21 SSD1306 OLED Support
    Monochrome I2C SSD1306 OLED support now working! Also you can swap L&R triggers or X&Y axes in the menu now.
    plus some random bugfixes for the menu flags
    [maple.c, menu.c]
2023-01-09 Update maple.c
    Fix firstboot vmu formatting issue
    [maple.c]
2023-02-23 Ellipse fill and button test screen
2023-04-05 Update maple.c
    reverting WIP antideadzone stuff; more important stuff to work on right now
    [maple.c]
2023-04-13 revert old wip stuff
    [menu.c]
2023-04-14 update sCal, iconData
    -fix stick calibration wizard
    -remove extra icon data
    [menu.c]
2023-04-14 deadzone work
    -tweaked stick/trigger calibration
    -working on deadzone adjustment menus
2023-11-29 arcade soft reset wip
    working on new lcd support, soft reset for arcade cab
    [maple.c, menu.h, sh8601.h]
2023-12-04 maplepad v1.5
    -hugely improved stick calibration (fully automatic)
    -deadzone and anti-deadzone adjustment for stick and triggers
    -autoreset with configurable timer and inter-maplepad communication for arcade cabinets
    -optimized display pixel-setting functions (reduces controller disconnects during saving)
    -fixed ssd1306 clearDisplay bug
    -added Settings menu controller type indicator
    -improved firstBoot behavior (now runs after a flashNuke and when updating from previous MaplePad versions)
    -implemented oledFlip for mono i2c oled
    -fixed upside-down mono oled splashscreen
    [maple.c, menu.c, menu.h]
2024-01-23 Create HW_LICENSE.txt
    solderpad license for hw

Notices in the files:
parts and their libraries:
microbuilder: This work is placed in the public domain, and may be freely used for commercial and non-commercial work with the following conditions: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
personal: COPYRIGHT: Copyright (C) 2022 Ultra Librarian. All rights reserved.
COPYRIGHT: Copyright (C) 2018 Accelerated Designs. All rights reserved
